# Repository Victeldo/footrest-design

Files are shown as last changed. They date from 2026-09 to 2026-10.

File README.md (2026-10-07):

# Flat-pack footrest — design and experiment history

**Looking for the parts to print? Start in [current/](current/README.md): the complete current set, materials, quantities and foot placement.**

Local engineering repository reconstructed on 2026-09-20 from supplied files, workspace artifacts and the user messages in this conversation. Each available design stage has its own chronological commit and tag. Commits use their actual creation time; they are not the original design timestamps.

Read [STATUS.md](STATUS.md) before using any print files, then [CHANGELOG.md](CHANGELOG.md). Each directory under `versions/` contains preserved artifacts and a `REVIEW.md` explaining the change, reason, evidence, outcome and next question. [CONTRIBUTING.md](CONTRIBUTING.md) sets the process for future iterations.

## Evidence and provenance

- `provenance/files.json` maps copied files to workspace paths and SHA-256 hashes. Paths are relative to the original project workspace, not this repository.
- Original files are copied without rewriting their contents. Some README files were annotated later in the project; they are preserved as found, not represented as exact release-day snapshots. Their print instructions can be obsolete.
- `archives/` retains original ZIP exports, which may contain earlier documentation than the unpacked artifacts. Historical print instructions are not current recommendations.
- Test observations in REVIEW files are retrospective summaries of user messages, not instrumented measurements. They distinguish local fit from assembled performance. Source reports preserve the recorded CAD evidence; this repository import does not rerun CAD, FEA or printer tests.
- V4 and earlier failed disconnected-brace versions have historical mentions but no standalone supplied geometry. No missing geometry or measured result has been invented.
- No GitHub remote, publication, license grant or external upload is implied. Existing local Git identity is used for the reconstruction, not claimed as authorship of all inherited geometry.

## Browse

`git log --oneline --reverse` shows the sequence. `git show <tag>` shows a stage's import and review. `git diff <old-tag> <new-tag> -- CHANGELOG.md` shows the recorded transition. Geometry snapshots have different paths: use `git diff --no-index <old-source.scad> <new-source.scad>` for a direct source comparison (exit 1 means differences).

Archived scripts vary in portability. Scripts named `validation_workspace.py` rely on original workspace paths. Do not assume relocating them makes them runnable. Preserved reference meshes and raw validation outputs are evidence, not additional parts to print.

Import audit: `provenance/output_coverage.json` accounts for every original output file by hash, including duplicate download folders. Original handoff files were also hash-verified. Large tool runtimes/caches and unrelated workspace scratch are intentionally excluded.

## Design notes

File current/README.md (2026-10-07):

# Current iteration — complete V10A print set

Start here instead of searching historical version folders. This folder collects the current assembly's parts; it is not a new geometry revision. Existing printed parts do not need reprinting.

## Print quantities

PLA:
- `PLA/01_top_PRINT_1.stl` — ONE top. Unchanged V7/V9 top; reuse yours.
- `PLA/02_left_support_PRINT_1.stl` — ONE V10A left support.
- `PLA/03_right_support_PRINT_1.stl` — ONE V10A right support. Do not print two lefts.
- `PLA/04_rear_brace_PRINT_1.stl` — ONE V10A side-entry rear brace.

TPU 95A:
- `TPU95A/05_foot_A_PRINT_2.stl` — TWO feet of variant A.
- `TPU95A/06_foot_B_PRINT_2.stl` — TWO feet of variant B.

Complete assembly: eight printed pieces. If your PLA assembly is already printed, only the four TPU feet are needed. Print TPU separately from PLA, with the orientations supplied and the settings that worked for your V6A shoe. A and B can share a TPU plate. Do not mirror or scale them in the slicer.

## Where the feet go

“Left/right” means viewed from the front of the footrest, facing toward the rear X-brace:

- Left support, front corner: A.
- Left support, rear corner: B.
- Right support, front corner: B.
- Right support, rear corner: A.

Thus A occupies one diagonal and B the other. Each support uses one of each. The window in the taller shoe wall aligns with the support's raised catch; on V10A these catches face inward. The closed shoe end goes at the outer end of the bottom rail. Seat the shoe and check the catch appears in the window; peel the window wall away deliberately for removal rather than forcing the PLA catch.

These are the original V6A-derived shoe geometries, preserved byte-for-byte from the V9 full pack. The mirrored V10A arrangement was checked on 2026-10-07: all four shoes can be positioned using ordinary rotations/translations (no new reflected print required), with zero nominal interference against the assembled structural parts. Physical fit on your actual V10A prints remains to be confirmed. This check is not a grip or fatigue test.

## Current experimental status

V10A reportedly substantially improved racking stability. The fully seated top reportedly binds during straight removal; packability remains unresolved. No load rating or measured 200 N qualification exists. Feet are for grip/floor protection, not a cure for structural racking. See [latest status](../STATUS.md).

## Provenance and updates

`manifest.json` records quantities, exact versioned sources and SHA-256 hashes. `foot_compatibility_checks.json` records the four rigid placement transforms and interference results. All six STLs are unchanged copies of their source version; only filenames and organization changed.

When a future iteration is accepted for testing, refresh this folder and quantities/manifest in the same commit. Preserve historical artifacts under `versions/`. Current means latest selected prototype assembly, not certified/final.

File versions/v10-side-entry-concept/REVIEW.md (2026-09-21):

# V10 side-entry concept — discussion model, not a print release

Parent: V9 bracket V2 and its assembled racking/lift-off failure. New concept created 2026-09-20. No physical tests have been run on V10.

## Agreed design boundary

Preserve the top where practical. Preserve the support frame and TPU interfaces where practical, but allow rear interfaces on both supports and brace to change. Reuse of existing support prints is a preference, not an acceptance criterion. User rejected purchased fasteners and chose investigation of inward-facing horizontal sockets. A stop added to the old drop-in system is not the selected path.

## Observation and hypothesis

V9/V2 upper channels slid upward off their rails during left/right racking. Smaller clearance improved stability but did not prevent the failure. Timing of initial channel lift versus initial racking remains unmeasured.

Hypothesis: restricting vertical movement at the brace attachment points removes a motion that defeats the rear X. Sideways sockets provide roofs and floors without a separate latch. The installed top must then restrain sideways support separation. This is conditional capture, not a positive lock against every combined motion.

## Concept geometry

Four rectangular brace tongues enter inward-facing blind sockets. Nominal tongue section 8 mm fore-aft by 16 mm vertical; 12 mm engaged length, with 2 mm clearance to each blind end. Socket section 8.3 x 16.3 mm. These 0.15 mm clearances are a starting concept value, NOT transferred validation from the differently oriented V9C coupon.

Socket block envelope is 20 x 23 x 24 mm. The roof/floor thickness is 3.85 mm; no strength claim follows from that dimension. Blocks overlap the original rear rail rather than replacing it. Gusseting, fillets, print orientation and material consumption are not finalized. The inward projection moves the X attachment centers closer together (144 mm across by 160 mm vertically); member forces must be re-evaluated rather than inheriting the V9 structural assumptions. X members remain nominally 8 x 6 mm.

Left and right support concepts are mirrored in assembled coordinates. This changes the handedness arrangement from the original identical-support V9 build. A print-orientation and TPU handedness review is still required; do not infer that existing shoes or two identical prints are already reconciled. The top uses the existing V7 geometry through the preserved source module.

## Assembly and force transfer

With the top off, bring supports inward around the brace. Each tongue slides sideways into its socket until its shoulder meets the mouth. Fit the top over the support tabs last. To disassemble, remove top and move supports outward.

Upward/downward tongue motion meets socket roof/floor after nominal clearance is taken up. Sideways withdrawal requires support separation. With the top held seated and rigid, its existing tab/socket walls oppose that separation. This is the reason to investigate the mechanism, not proof of assembled stiffness.

The top is not latched down. The CAD checks hold it seated/fixed when probing support separation and splay. They do not show whether racking can lift the top, rotate or flex supports, crack a roof, or gradually withdraw a lower tongue. That coupled motion is the remaining critical issue. A part with a closed socket can still have excessive angular or elastic compliance.

## Checks actually run

- Four rendered components: one connected, watertight, consistently wound mesh each.
- Assembled nominal overlaps: numerical zero.
- Both supports moving outward/inward 0–16 mm in 0.25 mm steps with brace fixed and top absent: no interference.
- Top installation over 0–40 mm in 0.5 mm steps: no interference.
- Deliberate brace displacement up/down by 0.5 mm: blocking contact at the sockets.
- Deliberate support outward movement of 0.2 mm with top fixed: blocking contact.
- Left-support rotation probes about its top at 0.1, 0.25, 0.5, 1 and 2 degrees also meet the fixed top. These are rigid geometric obstruction probes, not allowable-angle/stiffness predictions.

See concept_checks.json. No FEA, physical test, slicer review, deformable-contact simulation or print-size/orientation qualification is claimed. A clean nominal insertion path does not establish comfortable simultaneous insertion in a printed four-joint assembly.

## Deliverables and next decision

V10_assembly_sequence.png shows the actual mesh assembly stages and a nominal y=165 mm joint section. V10_CONCEPT_ONLY.glb is a reference model, not a printable file. V10_concept.scad defaults to the assembly and exports component geometry in assembled coordinates. No printable STLs have been released.

Before a coupon: examine combined top lift/support splay and finalize the mirrored support/foot arrangement and print orientation. The concept must constrain racking with the real top seated, allow intentional disassembly, and remain simple enough for repeated packing. If that cannot be achieved cleanly, reconsider the capture principle rather than rely on friction.

Rebuild nominal checks with `python build_and_check.py --openscad /path/to/OpenSCAD` after installing requirements.txt. It uses temporary mesh exports, writes the check report, and does not release print files.

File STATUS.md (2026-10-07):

# Current stage: V10A — user-reported assembled stability improvement

On 2026-09-21 the user reported that V10 largely resolves racking and feels much more stable. This is qualitative assembled feedback for the supplied V10A release, not a quantified strength or durability pass. V9/V2 failed racking/retention previously. No load rating exists.

## Current direction agreed with user

Keep the top where practical; allow support rear interfaces and brace to change. Stay fully printable, without purchased fasteners. Investigate horizontal brace tongues captured between inward-facing support sockets, with the top fitted last. Do not hard-constrain the design to existing support prints or resume tightening V9.

[Concept and evidence](versions/v10-side-entry-concept/REVIEW.md). The new sockets block vertical tongue movement nominally; the top blocks outward support translation only while held seated in the checked model. Combined top lift/support splay, flexibility, strength, printability and mirrored TPU arrangement are unresolved. V10A print-oriented STLs are released; initial assembled stability feedback is positive. See versions/v10a-print-prototype/START_HERE.md.

Preserve the current geometry. Next establish whether intentional disassembly/reassembly remains comfortable and the improved stability persists. Top lift, measured loads, sustained behavior, cycling and TPU installation were not reported. Do not infer they passed.

## Preserved constraints

A1 256 mm cube, PLA structure, replaceable TPU95A shoes, seated use, no standing. Existing top 240 x 170 mm, nominal overall height 241 mm. Calibrated top tabs 7 x 22 x 7 mm into 7.10 x 22.10 mm sockets. 200 N remains an unverified check target. Low filament waste, simple packing and deliberate easy disassembly are acceptance criteria.

## Latest packability observation

After fully seating the top, the user reports straight withdrawal feels locked and angling helps. This is not intentional latch behavior. Easy disassembly remains unresolved. Diagnose the actual binding location before changing the calibrated sockets, and avoid forceful extraction.

## Complete print set

Use [current/README.md](current/README.md) for all required parts and quantities. On 2026-10-07 the existing two A/two B shoes were verified geometrically on the mirrored V10A supports. No new foot geometry or physical fit result is implied.

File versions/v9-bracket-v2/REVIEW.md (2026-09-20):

# V9 bracket V2 with four 0p15 channels

Stage: `v9-bracket-v2`. Previous recorded stage: `v9c-fit`. Retrospectively documented 2026-09-20.

## Change and reason

Applied tested 0.15 mm fit to all four brace channels; X, spacing, top and supports unchanged. No anti-lift feature. About 0.53 g solid PLA added over prior brace.

## Recorded CAD/analysis evidence

Recorded one watertight component, A1 envelope, nominal assembly/removal/top-install checks. Regression against old brace plus four tighter coupons differed 0.00994 mm³ within documented 0.02 mm³ numerical tolerance.

## User-reported physical evidence

User printed V2: more stable, but during left/right racking the upper channels again slid up off the T rails. User emphasized that the brace still does not prevent racking.

## Outcome and next question

FAILED full-frame racking/retention despite improved local fit. Further tightening is not the established fix. Open question: when does vertical channel motion begin relative to frame racking? A proposed anti-lift feature must carry load and constrain racking, not merely catch a detached brace.

## Provenance caveat

Copied artifacts and archives are preserved as found. Some source READMEs contain later annotations or stale release instructions. This review and repository STATUS take precedence for interpreting current experimental status. No CAD or physical tests were rerun during this history import.

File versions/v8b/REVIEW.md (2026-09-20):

# V8B tether-eyelet keeper trial

Stage: `v8b`. Previous recorded stage: `v8`. Retrospectively documented 2026-09-20.

## Change and reason

Added receiver/keeper eyelets for cord retention. Initially considered TPU tether, but actual deliverable assumed cord; no TPU tether attachment was validated. Provisional rearward locations studied for key access.

## Recorded CAD/analysis evidence

Recorded joint mesh/path checks and four provisional key-clearance paths against top/support core. Attachment webs, full brace integration, tether motion and human access were not complete.

## User-reported physical evidence

No physical V8B pass reported. User questioned increasing complexity; assistant agreed keys/posts/tethers were overcomplicating the problem.

## Outcome and next question

Abandoned. Return to whole-assembly sequence and simpler connections rather than iterating an elaborate lock.

## Provenance caveat

Copied artifacts and archives are preserved as found. Some source READMEs contain later annotations or stale release instructions. This review and repository STATUS take precedence for interpreting current experimental status. No CAD or physical tests were rerun during this history import.

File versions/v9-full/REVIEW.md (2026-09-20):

# V9 full assembly with backed rail roots

Stage: `v9-full`. Previous recorded stage: `v9-trial`. Retrospectively documented 2026-09-20.

## Change and reason

Kept coupon contact geometry; added backing at each T root, with roughly 183 mm³ net added per support. Released full support/brace and unchanged top/TPU parts.

## Recorded CAD/analysis evidence

Recorded full topology/bed checks, four-joint assembly/removal and top installation, TPU nominal intersections, plus top/brace regressions. Root review was qualitative, not strength qualification.

## User-reported physical evidence

One support plus brace slid smoothly but swayed; user flagged this before printing second. Assistant expected the second support to constrain it. Complete assembly without TPU feet racked with all floor corners touching. Upper C channels slid upward off T rails; they did not spread/pop backward. User described the frame becoming a parallelogram.

## Outcome and next question

FAILED assembled racking/retention. Earlier confidence in the second support was unsupported. Floor grip was not the identified cause. Keep top/supports for experiments, not as a rated structure.

## Provenance caveat

Copied artifacts and archives are preserved as found. Some source READMEs contain later annotations or stale release instructions. This review and repository STATUS take precedence for interpreting current experimental status. No CAD or physical tests were rerun during this history import.

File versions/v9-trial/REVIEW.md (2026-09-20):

# V9 drop-in T/C coupon and full-layout concept

Stage: `v9-trial`. Previous recorded stage: `v8b`. Retrospectively documented 2026-09-20.

## Change and reason

Adopted four short T rails with C channels, fixed lower seating ledges and 20 mm vertical engagement. No latch. Beveled 45-degree shoulders for flat-print geometry; 0.30 mm per axis face. Narrowed ledge after detecting diagonal interference.

## Recorded CAD/analysis evidence

Recorded connected coupon/support/brace meshes, full approach/vertical paths and top install checks. Existing top explicitly did not block lift-off. Strength, uplift and four-point physical fit remained unknown.

## User-reported physical evidence

Coupon slid easily and remained wrapped during X/Y motion, with some rocking. User highlighted looseness. This was a local fit test only.

## Outcome and next question

Advanced to full prototype without proof of racking restraint. Later failures showed that easy fit and wraparound engagement were insufficient.

## Provenance caveat

Copied artifacts and archives are preserved as found. Some source READMEs contain later annotations or stale release instructions. This review and repository STATUS take precedence for interpreting current experimental status. No CAD or physical tests were rerun during this history import.

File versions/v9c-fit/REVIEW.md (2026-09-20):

# V9C brace-side clearance coupons

Stage: `v9c-fit`. Previous recorded stage: `v9-full`. Retrospectively documented 2026-09-20.

## Change and reason

Reduced only channel clearance to 0.20 and optional 0.15 mm per face, maintaining engagement, exterior, supports and top. No anti-lift stop added. Goal: distinguish excess clearance from the unrestricted release direction.

## Recorded CAD/analysis evidence

Recorded original-0.30 reproduction, single-solid tighter exports, added-material-only check, and nominal approach/vertical paths against support rail positions. No revised full-frame test at this stage.

## User-reported physical evidence

User reported 0p15 felt pretty good and authorized full bracket V2. Separate 0p20 result and explicit all-four-rail/cycle confirmation were not supplied.

## Outcome and next question

Local 0p15 fit selected. This did not prove racking or lift-off solved.

## Provenance caveat

Copied artifacts and archives are preserved as found. Some source READMEs contain later annotations or stale release instructions. This review and repository STATUS take precedence for interpreting current experimental status. No CAD or physical tests were rerun during this history import.

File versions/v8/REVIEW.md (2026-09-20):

# V8 sliding tongue and loose quarter-turn keeper

Stage: `v8`. Previous recorded stage: `v7`. Retrospectively documented 2026-09-20.

## Change and reason

Separated structural sliding tongue (0.30 mm per face) from quarter-turn withdrawal keeper. Added lift-to-turn locating posts and exposed grip to avoid forceful disassembly.

## Recorded CAD/analysis evidence

Recorded connected watertight meshes, sampled insertion/lift/rotation/extraction paths and deliberate blocking collisions. No load validation.

## User-reported physical evidence

No successful printed V8 trial reported. User flagged four loose keys as a loss/usability issue; print was canceled as the design changed.

## Outcome and next question

Abandoned before physical validation. Added operations/loose parts were unacceptable for packing.

## Provenance caveat

Copied artifacts and archives are preserved as found. Some source READMEs contain later annotations or stale release instructions. This review and repository STATUS take precedence for interpreting current experimental status. No CAD or physical tests were rerun during this history import.

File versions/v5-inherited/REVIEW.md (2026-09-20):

# Inherited V5 lightweight support and friction shoe

Stage: `v5-inherited`. Previous recorded stage: `v3-inherited`. Retrospectively documented 2026-09-20.

## Change and reason

Inherited 10 mm perimeter rails, 8 mm X members, 7 mm thickness and local junction pads. Handoff describes reduction from unavailable V4 (12 mm rails/10 mm braces). Existing TPU shoe relied on friction only.

## Recorded CAD/analysis evidence

Handoff reports a connected support and roughly 80.17 cm³ volume. Later V6A checks preserved the full bottom rail. No structural rating was established.

## User-reported physical evidence

No standalone V5 structural load result is available. User requested proper replaceable TPU retention.

## Outcome and next question

Use as structural starting point; replace friction-only foot interface without cutting the rail.

## Provenance caveat

Copied artifacts and archives are preserved as found. Some source READMEs contain later annotations or stale release instructions. This review and repository STATUS take precedence for interpreting current experimental status. No CAD or physical tests were rerun during this history import.

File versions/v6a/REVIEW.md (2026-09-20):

# V6A mechanically retained TPU foot

Stage: `v6a`. Previous recorded stage: `v6-calibration-inherited`. Retrospectively documented 2026-09-20.

## Change and reason

Added external PLA corner catches and mating TPU window shoes, keeping the bottom rail intact. Replaced friction-only retention with an intentional peel-to-release interface.

## Recorded CAD/analysis evidence

Recorded component/watertightness checks, material-preservation booleans, nominal contacts, rigid blocking checks and independent SCAD export comparison. Found inherited disconnected top bosses and 243 mm provisional height with sole.

## User-reported physical evidence

User printed shoe and PLA key/coupon, reported it fit and passed the tests. Small internal gap opposite the key slot was reported. Exact forces and per-test cycle counts were not supplied.

## Outcome and next question

Local TPU interface accepted for reuse; not full-structure validation. Next reconcile top/height and across-width bracing.

## Provenance caveat

Copied artifacts and archives are preserved as found. Some source READMEs contain later annotations or stale release instructions. This review and repository STATUS take precedence for interpreting current experimental status. No CAD or physical tests were rerun during this history import.

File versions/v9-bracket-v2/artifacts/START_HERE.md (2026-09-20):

# Rear bracket V2 — tested 0p15 fit

Print ONE PRINT_V9_bracket_V2_0p15_PLA.stl. It replaces the loose original V9 rear bracket. Keep your existing printed top and both supports.

All four channels now use the successful 0p15 coupon geometry: 0.15 mm nominal clearance per axis-aligned face, approximately 0.21 mm normal to the angled shoulders. Engagement remains 20 mm. X members, outside dimensions, joint spacing and assembly orientation are unchanged. No latch or anti-lift stop has been added.

## Print

Use the same PLA and slicer settings as your successful 0p15 coupon. Preserve the supplied orientation: flat X/back face on the bed, channels facing up. Size: 217 x 180 x 13.6 mm, within the A1 envelope. Inspect the sliced shoulder overhangs and channel openings. No new sliced toolpaths were generated or verified here. Solid-volume estimate is approximately 45.4 g; actual filament use comes from your slicer. The change adds about 0.53 g solid PLA over the previous bracket.

If you have not already done so, try the successful 0p15 coupon on all four actual rails before starting this larger print. Do not force it onto a rail that differs from the one originally tested.

## Assemble and evaluate

Remove the old rear bracket. With the top removed, align all four channels about 21 mm above their seated positions, approach from behind and lower straight down onto the stops. Guide at the joint blocks; do not bend the X to force four-point alignment. Install the existing top. All four channel backs should rest on their ledges.

Before applying foot load, gently alternate sideways pressure with the assembly on a flat floor. Compare racking against the original bracket and watch the upper AND lower connections for upward movement. Stop for climbing, binding, cracking, whitening or a floating corner. Confirm hand removal remains practical, supporting the side frames while lifting the bracket.

A closer local fit does not prove full-frame stiffness or anti-lift behavior. If V2 still climbs, reduced clearance alone has not solved retention. No 200 N capacity or normal-use qualification is claimed. Report seated play, racking, corner lift and removal effort before further load testing.

## Geometry validation

The exported and reloaded bracket is one connected watertight solid with consistent winding. All four nominal channels clear the current supports in the assembled position and sampled 21 mm vertical release/raised rear approach paths (0.25 mm increments). The existing top's installation path was sampled at 0.5 mm increments. All collision checks returned zero volume.

The full mesh was compared against the old brace unioned with four copies of the tested 0p15 coupon. Symmetric difference was 0.00994 mm³ over roughly 36,600 mm³, within a 0.02 mm³ numerical tolerance for STL/float coordinate rounding. This verifies the intended channel-only revision to mesh precision. See geometry_checks.json for dimensions, checks and hash.

Source: V9_bracket_V2_0p15.scad is self-contained and exports the full bracket directly. validation_workspace.py records the validation using the existing project reference meshes; it is not a standalone rebuild tool.

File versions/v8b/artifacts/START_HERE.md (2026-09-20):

# V8B: tethered-key usability trial

V8's loose-key trial is superseded. This is one small joint coupon, not a full footrest release. The current working assumption is a short cord tether; no TPU tether attachment has been validated or released.

## What changed

A 4 mm eyelet was added outside the receiver socket wall. A 3 mm eyelet was added through the keeper handle tip, away from its central shaft. A cord tied between these eyes keeps the key attached after removal, including when the parts are turned upside down. The tether carries only the loose key, not structural brace loads. It is replaceable by untying/cutting the cord. It does not prevent the unlocked key from dangling and does not make the lock vibration-proof.

The sliding tongue, 0.3 mm clearance per face, quarter-turn crossbar and lift-to-turn locating posts are unchanged. No support rail, top connection or TPU foot interface has been cut or revised.

## Print one joint

Print one each: V8B_trial_receiver.stl, V8B_trial_tongue.stl, V8B_trial_keeper.stl. All PLA, same plate, normal by-layer printing. Keep supplied orientations. Starting profile: 0.4 mm nozzle, 0.2 mm layers, 6 walls, 5 top/bottom layers, your previous PLA settings. No supports intended; inspect the 12.6 mm receiver cavity bridge, 12.2 mm tongue opening bridge, and smaller keeper/eyelet openings in the slicer. Geometric printability has been reviewed, but no slicer/toolpath or physical print validation was performed here.

Total solid-volume estimate: 13.7 g PLA at 1.24 g/cm³; use the slicer for actual consumption. Do not print full-size replacements yet.

## Fit and tether test

1. Check that the tongue slides freely in and out of the receiver with the keeper absent. Stop if it wedges; do not hammer it.
2. Insert the keeper across the elongated hole, leaving the handle about 1.8 mm above its seated position. Turn 90 degrees and lower between the posts. A gentle withdrawal tug should be blocked.
3. Lift about 2 mm, turn back, and remove the keeper; then slide the tongue out. Repeat a few times before fitting a tether.
4. Use flexible cord around 0.8–1 mm diameter. Tie one end through each eyelet, leaving approximately 60 mm of free cord between attachments plus sufficient knot tails. This length is a starting trial value, not a tested optimum. Tie around the eyelet material rather than relying on a small stopper knot being larger than the hole. Tug-check each attachment. Keep knots outside the locking surfaces.
5. Repeat ten lock/release cycles with the cord attached. The keeper must lift and turn without pulling the tether taut, and the cord must not enter the tongue socket or locating posts. The released keeper should stay attached when the coupon is inverted and gently shaken. Check the knots and eyelets afterwards.
6. Report finger effort, whether two hands feel awkward, any cord snagging, and whether locked/unlocked is easy to identify. Stop for whitening, cracking, wedging, or a loosening tether. These are usability trials, not body-weight tests.

When locked, the handle runs along the tongue's sliding direction and sits down between the posts. When released, it turns across that direction. This orientation is the current visual/tactile cue; printed LOCK labels and a stow position are not yet implemented.

## Validation completed

All three meshes are watertight, consistently wound, one connected component each, with positive volume. Largest part dimension is 32.3 mm. Sampled joint insertion, lift, rotation and extraction have no significant Boolean overlap (numerical residue under 1e-12 mm³). Deliberate wrong-direction tests confirm geometric blocking of tongue withdrawal, excessive locked lifting and seated rotation. See geometry_checks.json.

Four provisional receiver origins are [25.55 or 221.55, 168, 33 or 193] mm in assembled coordinates. At all four, the sampled keeper release paths clear the existing top and unchanged support cores/rail stiffeners. Retired V7 rear sockets are omitted from that context. See layout_checks.json and V8B_access_study.png. The illustration omits the new brace and attachment webs; the receivers are not integrated structural parts.

This is NOT a completed four-joint assembly validation: new connecting webs and brace, tether motion, human finger access, and strength are still outstanding. Moving receivers rearward creates a larger offset from the rail, so the attachment must resist the corresponding bending moment. Their supports must be designed before full-size export. The upper connector path clearing the top does not alone prove comfortable hand access.

The tether does not improve tongue/keeper strength. The 2.9 mm tongue ligaments beside the opening remain a structural trial detail. Neither V8 nor V8B establishes the provisional 200 N footrest capacity. Once usability is acceptable, the full assembly needs reinforcement, geometry checks, print review and physical loading checks.

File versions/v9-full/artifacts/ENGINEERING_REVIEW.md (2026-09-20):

# V9 full-prototype joint review

## What the physical trial established

The channel slides on by hand, remains wrapped around the rail while moved in X/Y, and can rock slightly. This supports retaining the current clearance for the full-assembly experiment. It does not quantify stiffness, four-joint alignment, uplift behavior or strength. More contact points do not eliminate clearance.

## Root and shoulder decisions

The 20 mm-long engagement, 14 mm T head, 7 mm stem, 3.2 mm channel side walls and 6 mm rear wall are retained. Nominal clearance is 0.3 mm per axis-aligned mating face and about 0.42 mm normal to the 45-degree shoulders. The section is constant along the vertical sliding direction; it does not wedge tighter as it seats.

The C shoulders oppose backward separation by bearing on the T shoulders. Their slope produces a spreading component in the channel walls, so shoulder/root cracking remains an inspection item. Side faces transfer across-width forces. The short 11 x 6 mm nominal seating patch on each ledge stops downward travel, but cannot provide tensile vertical restraint. Four such joints therefore cannot be modeled as four fully fixed or pinned connections: upward contact can open.

A 10.5 x 6 x 26 mm backing envelope is added to each rail root, mostly overlapping existing support material. It connects the previously short embedded stem to more of the rear rail. Its rear edge stops at the original rear-face plane; the moving channel starts 0.7 mm behind that plane. Only about 183 mm³ net material is added per support. This is a geometric load-path improvement, not a measured strength gain. No mating face or existing support member is cut.

The original 8 x 6 mm X members are retained in the brace, with a fused central crossing and broad overlap into the four channel backs. These distribute racking through axial forces and local bending, but slip and uplift may dominate apparent stiffness. The existing top geometry and calibrated tab/slot fit are preserved.

## Why this is a prototype release

The full model has no interference along the intended assembly paths. Connectivity and bed envelopes have been checked. That is enough to build the assembly-test prototype following the successful local fit test. It is not enough to assign a load rating.

No FEA, printed-material allowable stress, fatigue qualification, creep prediction or anti-lift validation was performed for this release. The earlier V7 idealized frame calculation assumed more constrained joints and cannot establish the V9 gravity-seated frame's stiffness or strength. In particular, neither self-weight nor a nominal 20 mm engagement proves that a connection cannot climb under cyclic racking.

The useful next observation is the assembled response: four-point seating, clearance take-up versus elastic movement, and any upward motion of a corner. If the frame climbs, a simple anti-lift provision would be justified by observed behavior; it has not been added preemptively.

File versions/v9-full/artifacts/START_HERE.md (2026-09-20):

> ASSEMBLY TEST FAILED: user reported racking and upper channels lifting off. Do not reprint the unchanged brace as a fix. Current next step: ../V9C_fit/START_HERE.md. Existing top/supports are retained for the fit revision.

# V9 full-size assembly-test prototype

The user-tested drop-in fit is retained. The channel and full brace are geometrically identical to the V9 concept. Each T rail now has a backing pad extending 6 mm into the rear rail region and 3 mm above/below its engagement, without entering the sliding channel. No separate key, cord or latch is required. No original rail material was removed.

## What to print

- V9_support_PLA_PROTOTYPE.stl: TWO identical copies, 164.3 x 230 x 14 mm. Print the first support and brace before committing the duplicate.
- V9_brace_PLA_PROTOTYPE.stl: ONE, 217 x 180 x 13.6 mm.
- V9_top_PLA_PROTOTYPE.stl: ONE, 240 x 170 x 24 mm. This is unchanged from V7; reuse an intact V7 top if already printed.
- V9_foot_left_TPU95A.stl and V9_foot_right_TPU95A.stl: TWO of each for four feet total. Reuse matching successful V6A/V7 feet. These interfaces are unchanged.

All STLs are in millimetres and oriented for printing. Do not mirror one support: both supports have their raised printing faces pointing in the same global direction in the assembled model. The brace is asymmetric through its thickness and aligns with these identical supports.

Use the material/profile that produced the successful V9 coupons, preserving their orientation-dependent fit. If using the previous baseline: 0.4 mm nozzle, 0.20 mm layers, 6 walls, 6 top/bottom layers, 20–30% infill. These are starting settings, not a strength qualification. Print TPU separately with your successful settings. No multi-material purge tower is needed.

The top prints smooth face on the bed. Supports print original flat face down. The brace prints its flat X/back faces on the bed, channels facing up. Inspect the channel shoulders, stop ledges and root additions in sliced preview. The coupon established the local fit/print approach, but the new backing pads and whole parts have not been physically printed. The short ledges include local overhangs; no automatic support generation or slicer validation was performed. Do not add supports inside the sliding surfaces without checking their effect on fit.

Center the 240 mm top: it leaves only 8 mm nominal margin on each side of the 256 mm plate. Check brim and exclusion areas. Do not scale any part. Each large part should have its own plate unless the slicer verifies another arrangement; printing two supports together is not assumed feasible.

Actual filament consumption must come from the slicer. The earlier reported V7 masses are historical, not V9 predictions. The root backing adds only about 0.23 g solid PLA per support over the V9 concept.

## Low-waste print order

1. Print one support and the rear brace. Engage both joints on that one support, then lift the brace off. Check simultaneous seating, easy removal and no root whitening. Do not use the cantilevered brace as a lever or load this partial assembly.
2. If both joints slide and seat as expected, print the second identical support. Reuse or print the unchanged top and TPU feet.
3. Assemble the complete prototype and assess whole-frame behavior below. No further isolated coupon is requested.

## Assembly

Fit one left and one right TPU shoe to each support. Place both supports upright with their rear T rails at the same rear edge, and both raised printing faces pointing the same global direction; use the assembly image as the orientation reference. Hold them about 196 mm apart at their center planes.

With the top off, align the brace channels roughly 21 mm above their seated positions. Approach from the rear and lower all four channels together onto their stops. Guide at the joint blocks rather than bending an X member to force alignment. Install the top over the four calibrated tabs; the support shoulders should seat against the top.

The four C backs should sit on their ledges. Print variation may prevent perfect four-point seating; if one corner floats, report it instead of forcing or sanding the assembly immediately. Reverse the sequence for packing: remove the top, support the side frames, lift the brace about 21 mm and separate.

The top does NOT positively block brace lift-off. Lift-off is the intended release mechanism. Carry disassembled or support the components together; do not assume lifting by the top or brace retains the rest.

## Full-assembly evaluation

First check all four feet touch a flat floor and all top shoulders and brace stops seat. With hands at the top, gently alternate lateral pressure in both directions while watching each C channel. Distinguish a small initial clearance take-up from continuing flex, clunking or a corner rising off its stop. Record a short view of the rear if the motion is difficult to describe.

Stop for joint climbing, increasing movement, whitening, cracks or an unseated top. If the assembly remains stable, introduce seated heel pressure gradually while keeping your weight on the chair and inspect again. Do not stand on it. This initial check does not certify the provisional 200 N target, cyclic durability or long-term creep. An agreed measured-load test can follow the seating/racking results; normal use is not yet validated by CAD.

## Completed checks

Each exported mesh was reloaded and verified as one connected, watertight component with consistent winding and positive volume. All object envelopes fit the A1 bed. Nominal full-assembly interference is numerical zero, including all four TPU feet. Vertical brace travel and raised rear approach were sampled every 0.25 mm; top installation every 0.5 mm. No collision was found. The brace and top were Boolean-compared against their previous versions and are identical.

These checks do not simulate printed tolerances, human assembly force, elastic deformation or layer strength. See geometry_checks.json for measurements and hashes, ENGINEERING_REVIEW.md for joint reasoning, and V9_full_assembly.png for orientation.

## Rebuild

Install OpenSCAD and the Python packages in requirements.txt, then run `python build_and_validate.py --openscad /path/to/OpenSCAD`. This rerenders the five parts, repeats validation and writes the STLs/report next to the source. The reference meshes are regression inputs, not additional print parts.

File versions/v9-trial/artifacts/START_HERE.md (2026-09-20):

# V9: drop-in T-and-C joint — print these two coupons only

V8 and V8B keys/tethers are superseded. V9 uses four short rails, four integral brace channels and fixed seating ledges. No loose fasteners, flexing latch or wedge fit. The existing top does NOT trap the brace: it can lift off. This is a gravity-seated concept, not positive anti-lift retention.

## Print

Print one PRINT_FIRST_V9_rail_coupon.stl and one PRINT_FIRST_V9_channel_coupon.stl. Both PLA, same plate, normal by-layer printing; retain supplied orientations. Start with your existing PLA profile, 0.4 mm nozzle, 0.2 mm layers, 6 walls, 5 top/bottom layers. Supports are not intended. Review the slicer: the 45-degree internal shoulders replace unsupported square lips. The rail has separate initial bed-contact regions that merge as printing progresses; check bed adhesion. No slicer/toolpath verification has been performed here.

Together the coupons contain 8.48 cm³, about 10.5 g if solid PLA at 1.24 g/cm³. Actual slicer consumption depends on settings. Do not print the full support/brace context selectors yet.

## Test

1. Hold the rail upright: its long 20 mm engagement runs vertically, and the seating ledge is at the bottom.
2. Put the channel above the rail, with its narrow opening facing the rail stem. Lower it straight down until its solid back lands on the ledge. Do not push it on from the rear at the seated height.
3. Lift roughly 21 mm to clear the rail completely, then separate. It should be finger-easy in both directions. No hammering, prying or forceful snap is intended.
4. Repeat ten cycles, checking for rough sliding, binding, whitening or wear. Report whether it falls into place under its own weight or requires light hand pressure, plus side-to-side/backward play.
5. Gently pull straight backward while seated: the shoulders should prevent separation. Gently push downward: the ledge should stop travel. This is only a fit/handling test; do not load it with body weight.

Do not sand extensively to make it pass without reporting that: the goal is to assess the printed clearance. A single joint passing does not prove four simultaneous joints will align or remain seated under racking.

## Mechanics and dimensions

T head: 14 mm across, 4 mm rear portion; stem: 7 mm. Vertical engagement: 20 mm. C outer width: 21 mm. Side wall thickness beside the head: 3.2 mm; rear wall: 6 mm. Axis-aligned mating faces have 0.3 mm clearance per face; matching 45-degree shoulders have approximately 0.42 mm normal clearance. These are uncalibrated trial values. The joint is constant-section along its travel, not tapered to wedge tight.

The angled shoulders preserve wraparound retention while improving flat-print overhangs. They can also spread the C walls when loaded backward; wall/root strength requires physical assessment. Fillets and local reinforcement remain candidates before final structural release.

The T attachments add material behind the existing rail rather than cutting into it. Their offset still creates bending at the attachment root: unchanged rail material does not prove unchanged strength. The top interface and V6A foot geometry remain unchanged. Both supports use the same orientation, matching the existing design.

## Geometry validation

Both coupons, the full support concept and full X-brace concept are each single connected, watertight meshes with consistent winding and positive volume. Print envelopes fit the A1: support 164.3 x 230 x 14 mm; brace 217 x 180 x 13.6 mm. See geometry_checks.json.

Boolean checks sampled 0.25 mm steps over the 21 mm vertical engagement/release path and raised rear approach, for the coupon and all four full-assembly connections together. No interference remained. Top installation was checked at 0.5 mm increments over 30 mm; the assembled top/support/brace do not interfere. Deliberate 0.5 mm downward, 1 mm backward and 1 mm sideways motions produce contact/interference as expected, establishing the ledge and wraparound geometry. These checks are nominal rigid CAD checks, not print-tolerance, strength or fatigue proofs.

An initial upper-stop/diagonal clash was corrected by narrowing the stop to 11 mm. The rear wall has a nominal 11 x 6 mm seating patch. The stop is not a latch.

## Full assembly sequence and remaining work

With the top removed, hold the brace 21 mm above its seated location, approach the supports from behind, align the four channels and lower onto the stops. Install the top. Reverse to pack. The current geometry also permits upward brace removal with the top present; no anti-lift benefit is claimed from the top.

After coupon fit succeeds, check simultaneous four-joint alignment and seating, then assembled racking and corner lift. Vertical seated-foot loading alone does not establish rear-brace stability. The 200 N target is not a tested rating. Full-size release is withheld pending fit feedback and further root/shoulder/load review.

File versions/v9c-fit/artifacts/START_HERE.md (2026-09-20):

# V9C: tighter C-channel fit tests for the EXISTING printed supports

The full V9 assembly racked and its upper C channels slid upward off their T rails. All floor corners contacted the ground. This is a failed assembled-brace test, not a TPU-foot issue. The printed top and supports are retained for this iteration; that does not establish their load capacity.

## Print only the 0p20 channel first

V9C_channel_0p20_PLA.stl reduces nominal axis-aligned clearance from 0.30 to 0.20 mm per face. Head pocket width changes from 14.6 to 14.4 mm, stem opening from 7.6 to 7.4 mm. The corresponding 45-degree shoulder normal gap changes from about 0.42 to 0.28 mm. This is an adjustment to BOTH lateral and fore-aft mating surfaces, not uniform scaling.

Use the same PLA, layer height, line widths, wall settings and supplied orientation as your full V9 brace. Flat back on the bed, channel upward. Do not rotate it upright, scale it, or sand mating surfaces before assessing the result. If the slicer requests mesh repair, stop and report that. The solid-volume estimate is 4.64 g at 1.24 g/cm³; actual slicer consumption may differ.

V9C_channel_0p15_PLA.stl is an optional tighter fallback, not a request to print both immediately. It uses 0.15 mm per face (14.3 mm head pocket, 7.3 mm stem opening, approximately 0.21 mm bevel-normal gap), about 4.69 g solid. Layer quantization and extrusion variation mean a 0.05 mm nominal change may not produce a distinct fit on every surface. Compare sliced layers if the two prints feel identical.

The pieces have no physical size labels. Print individually or label their exterior immediately if printing both. No new T-rail coupon, support or top is needed.

## Test against all four actual rails

Remove the top and rear brace for access, and hold each support securely. Slide the single test channel downward over a T rail to its ledge, then lift it off. Do not snap it on from the rear. Repeat on all four T rails, keeping track of support and upper/lower position.

The goal is easy finger-operated sliding with clearly less sideways/backward movement when seated. Hold close to the channel rather than applying leverage. Compare with the original loose coupon if available. Some upward sliding is unavoidable and intended; this test does not create an upward lock.

Repeat approximately ten cycles on each rail if initial movement is easy. Stop if it jams, needs force, shows whitening/cracks, or scrapes heavily. A fit that is good on three rails but binds on the fourth is not suitable for a four-channel brace. Do not force the tighter 0p15 part if 0p20 is already tight.

If 0p20 is comfortably removable on all four rails and removes most seated play, report that result; there is no need to chase the smallest number. If it is still clearly loose, try 0p15. Report insertion/removal effort, seated play and any difference among the four rails.

## What changed and what did not

Only the C-channel cavity shrinks. Exterior envelope remains 21 x 20 x 13.6 mm in print coordinates; engagement stays 20 mm. Material is added to the inner faces, not removed from structural walls. No latch, taper, extra fastener, support modification or top modification is introduced.

The 0.30 parameter version was Boolean-compared with the original V9 coupon and reproduces it. Both tighter exports are one connected, watertight mesh, with consistent winding and positive volume. Nominal approach and 21 mm vertical travel against the current full support at both joint heights were sampled every 0.25 mm with zero overlap. Intentional sideways/backward/downward overtravel produces blocking contact. Exported STLs were reloaded and checked. See geometry_checks.json.

These checks do not predict printed friction or deformation. No sliced toolpaths, material strength or full revised-brace test is claimed. Because the supports are identical, one nominal support geometry covers both sides; the physical test still needs all four printed rails.

## Next decision

After selecting the loosest variant that gives acceptable play and easy release across all four rails, update the full brace only, recheck its geometry and test the assembled frame again. A local fit test cannot demonstrate that four joints will register without binding or that the frame will resist racking.

Reduced clearance may reduce motion leading to lift-off. It does not physically prevent upward disengagement; continued climbing in the full assembly would mean this approach is insufficient. No replacement full-brace STL is released in this pack yet. Do not resume loading the loose V9 assembly pending the revised-brace test.

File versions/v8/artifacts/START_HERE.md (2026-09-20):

> SUPERSEDED: loose-key print canceled. See ../V8B/START_HERE.md for tethered-key trial status.

# V8 rear joint: print one small trial set

The V7 rear joint is retired after the printed brace key broke during removal and remained stuck in the support. Both prints are discarded. This release tests a new mechanism; it does not contain replacement full-size supports or a brace.

Print one each of V8_trial_receiver.stl, V8_trial_tongue.stl, and V8_trial_keeper.stl. All three are PLA and can share one plate with normal by-layer printing. No material changes or purge tower are needed. Keep the supplied orientations so the trial represents the intended structural parts. Use the same PLA/profile used previously, a 0.4 mm nozzle, 0.2 mm layers, 6 walls, and 5 top/bottom layers. Supports are not intended; inspect the small bridges in the slicer and after printing. Total solid-volume PLA estimate is 13.5 g at 1.24 g/cm³; use the slicer for actual consumption including brim/purge.

## Why this mechanism

The rectangular tongue has 0.3 mm clearance on each mating face (0.6 mm total). Its broad faces transfer brace loads through bearing contact. A separate quarter-turn keeper prevents withdrawal. This avoids requiring a structural tongue to be both an extremely tight fit and a hand-removable fastening.

The receiver is open-ended for inspection. The keeper's head seats between four posts, which obstruct rotation until the head is lifted. Its lower crossbar catches beneath the receiver when locked. This is a gravity-seated keeper, not a spring-latched or vibration-secured fastener: inverted transport retention is not established. For flat packing, remove and store the keeper separately.

## Trial sequence

1. Inspect bridges and remove only loose strings or brim. Record any sanding needed; extensive fitting would defeat this clearance test.
2. With the keeper removed, slide the blue tongue into the grey receiver until its broad pad meets the end. It must slide in AND out using fingers. If it wedges, stop; do not hammer or force it.
3. Align the keeper's long head and lower crossbar across the receiver's width, matching the elongated through-hole. Insert from above until the head remains about 1.8 mm above its seated height. The lower crossbar must have passed below the receiver.
4. Turn 90 degrees so the head runs along the tongue's sliding direction, then lower it between the indexing posts. A gentle withdrawal tug should be stopped by the keeper. Some clearance/play is intentional.
5. Lift the head about 1.8 mm (roughly 2 mm), turn 90 degrees back, and pull the keeper up and out. Then slide the tongue out. If the head will not rotate, inspect whether it clears the posts; do not twist forcefully.
6. Repeat 10 cycles. Report sliding effort without keeper, ease of lifting/turning/removing the keeper, play when locked, and any whitening, cracks, or wear. No body-weight test on this coupon.

See V8_release_sequence.png. Colors identify components only; one PLA spool is sufficient.

## Completed validation and limits

All three exported STL meshes have one connected component, consistent winding, positive volume, and are watertight. Largest dimension is 28 mm. Boolean overlap checks found zero collision at the assembled position and along sampled straight insertion (0.25 mm), lifting (0.05 mm), turning (0.5 degree), and keeper extraction (0.1 mm) paths. Deliberate out-of-path checks confirm tongue withdrawal by 1 mm hits the locked keeper, lifting the locked keeper by 3 mm catches the underside, and turning the seated handle by 15 degrees hits the indexing posts. These positive collision checks establish nominal geometric blocking, not strength.

The supplied receiver orientation includes a 12.6 mm tongue-cavity bridge and a 6.6 mm keeper-hole bridge. The tongue has a 12.2 mm keeper-hole bridge. These surfaces can reduce real printed clearance: inspection and the physical trial remain necessary.

The 18 mm tongue retains 2.9 mm of material on each side of its 12.2 mm-wide keeper opening. This is an intentionally small mechanism trial; neither those ligaments nor the receiver's attachment to a full support have passed a structural load test. Geometry checks do not establish fatigue life, impact strength, or the project's provisional 200 N vertical capacity.

If the trial passes, integrate the receiver into new full-size supports and the tongue into a rear brace, then validate the complete assembly, reinforcement, print orientation, release access, bed fit, and load path. The previously tested top connection and V6A TPU interface remain unchanged. Do not print another V7 rear connection.

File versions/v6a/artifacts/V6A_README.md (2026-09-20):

# V6A retained TPU corner foot — first physical trial

This is a coupon-stage design, not a validated final foot or full footrest. Print **one PLA coupon and one TPU foot**, inspect the fit, and return the observations below before printing full supports or duplicate feet. The supplied handoff was read before source and mesh inspection; its historical decisions were treated as design context. Original files are unchanged.

## Files and current status

- `V6A_PLA_corner_coupon.stl`: 32 × 22 × 9.2 mm representative bottom-left corner. PLA, flat original support face on bed, catch facing up.
- `V6A_TPU95A_test_foot.stl`: 29.8 × 11.1 × 16 mm in supplied print orientation. TPU 95A, sole on bed. No rotation or scaling needed.
- `V6A_retained_foot.scad`: editable native geometry. Default `part="coupon"`; use `"foot"`, `"coupon_assembly"`, `"support_reference"`, or `"support_assembly"`. The full support selectors are previews, not instructions to print a complete support yet.
- `V6A_interface_review.png`: mesh-derived views and cross-section.
- `geometry_checks.json`: baseline and new-part measurements and exact-solid intersection tests.
- `source_export_checks.json`: independent OpenSCAD 2021.01 export checks against the generated meshes.
- `reference/`: unchanged input files, for provenance only. Do not print the obsolete V5 foot or V3 top from this folder.
- `validate_and_build.py`: reproducible Manifold/Trimesh generator and geometry checks using the reference STLs. Dependencies are listed in `requirements.txt`. Run in a virtual environment with `python validate_and_build.py`; intermediate outputs go in `work/`. This validates default dimensions. Parameter edits in SCAD must be exported and checked anew; they do not automatically change the Python construction.

## Why this connector

The full 10 mm-high × 7 mm-thick V5 bottom rail, braces, gussets and top tabs are retained. Two small catches are added on the support's upper printing face, one near each lower corner. The catch root overlaps the existing material by 0.2 mm, so this is a solid union, not touching shells. No hole, slot, notch or rail thinning is introduced.

A groove cut into a thin rail can remove material from an important bending section and create a stress concentration. An external catch avoids that section loss. It still needs a physical test for catch-root damage and layer adhesion; preserving the rail section is not a load-rating calculation.

Each TPU shoe has a 2 mm sole, side walls, an outer-end stop and a through-window. The PLA bottom bears directly on the TPU sole. The catch is unloaded by ideal downward compression and primarily retains the shoe during lifting or dragging. In-plane handling forces meet the end stop or catch/window edges. The opposite side wall restrains motion across the 7 mm rail thickness.

The catch has a 45° entry ramp and a roof-shaped retaining edge. The window follows that retaining edge with nominal 0.25 mm vertical clearance, distributing capture across its width. Pull-off requires the window wall to flex outward over the catch, rather than merely overcoming surface friction. For replacement, deliberately peel that wall outward and withdraw the shoe toward the floor. This is positive geometric retention, but release force and fatigue are not yet established.

The roof-shaped window narrows to a 2 mm bridge at its top. This avoids asking TPU to bridge the full 10.5 mm window width. The PLA catch grows from the upward face during printing and needs no underside support. Slicer inspection is still needed to confirm the roof and ramp toolpaths with your profile.

## Nominal fit dimensions

- Rail remains 7.00 mm thick. Shoe channel is 7.50 mm wide: 0.25 mm clearance per face.
- Catch spans x = 9–19 mm from the outer corner; it rises 2.2 mm beyond the PLA face.
- TPU window wall is 1.8 mm thick; its inner face is at z = 7.25 mm.
- Passing the catch therefore requires up to 9.2 − 7.25 = **1.95 mm local outward displacement**. This is displacement, not a measured strain or installation-force prediction. The constrained TPU wall bends and stretches nonlinearly.
- Sole nominal contact with PLA is 28 × 7 = 196 mm² at each foot; actual floor pressure depends on load, sole deformation and the printed surface.
- Existing top tabs remain **7 × 22 mm, 7 mm engagement**, centers 39 and 111 mm. The historical **7.10 × 22.10 mm socket decision is preserved**. Its PLA/PLA fit does not calibrate TPU clearances.

## Geometry evidence

Checks use Manifold3D solid booleans plus Trimesh STL topology checks; the native SCAD was also compiled independently in OpenSCAD 2021.01 and compared with the generated solids. STL exports were reloaded and checked.

- V5 support: one watertight connected body, 80.1749 cm³.
- Modified reference support: one watertight connected body, 80.4191 cm³, 150 × 241 × 9.2 mm envelope. Original V5 material removed: **0 mm³**. Two catches add 244.2 mm³ (0.2442 cm³), about 0.30 g PLA at an assumed 1.24 g/cm³, or 0.30% added solid volume.
- PLA coupon: one watertight connected body, 3.8213 cm³, about 4.74 g fully solid PLA at 1.24 g/cm³.
- TPU foot: one watertight connected body, 1.8670 cm³, about 2.24 g fully solid TPU at an assumed 1.20 g/cm³. Use your spool density for a better estimate.
- Zero seated solid overlap for the coupon/foot, full support/left foot, full support/reflected right foot, and foot/foot pairs. The rail underside and sole touch intentionally; lateral assembly gaps are 0.25 mm nominal.
- Translating the seated shoe down 1 mm produces 13.5 mm³ collision with the catch. Translations of ±1 mm along the rail and ±1 mm across it also collide with the support. These checks demonstrate obstructions to straight rigid translation, **not** a measured retention force or proof against every combined rotation/peeling path.
- A rigid insertion sweep intentionally intersects the catch. The wall must flex during assembly; this is not a collision-free rigid sliding joint.
- Both support positions were transformed into the original V3 assembly coordinates. Their tab locations align with the nominal sockets, and solid top/support overlap is zero. This does not establish functional socket walls or validate the top structure.
- Both coupons fit easily inside the stated 256 × 256 mm bed. The reference support's 150 × 241 mm flat footprint fits the nominal bed, leaving only 15 mm total in its long direction before brims and printer exclusions.

No FEA, strength certification, fatigue test, floor-grip test or printer-specific slicing was performed. Filament masses above are solid-volume estimates, not slicer predictions.

## Inherited issues found during inspection

**Height:** V5 reaches 241 mm from bare rail bottom to tab top. The V3 platform is positioned with its top at the same height. Adding this sole yields **243 mm uncompressed overall height**, not 241 mm. This trial deliberately leaves V5's structural height and calibrated engagement unchanged. After foot fit succeeds, reconcile nominal overall height with the top. One possible later revision is reducing support body height by the sole allowance while retaining 7 mm engagement; that would require new brace/junction and assembly validation. Actual loaded height also depends on TPU compression.

**V3 top:** the supplied STL is watertight but has **five disconnected bodies: the platform and four separate socket bosses**. Each boss ends at about z = −0.01 mm; none is joined to the platform. Its lightening cuts and boss/socket region need inspection and repair before a full top print. Watertightness alone is insufficient. This inherited top is not modified or endorsed by the present connector trial.

**Historical tolerance coupon:** the supplied mesh reports non-watertight geometry and 24 components under the current parser. This does not negate the reported physical fit experiment. The selected tab/socket fit is retained; re-export/repair that mesh if it is needed again.

**Handedness:** the delivered test foot is for the illustrated corner. The opposite corner uses a reflected shoe. Reflection was included in the assembly checks, but a duplicate production batch has not been released. Do not assume four identical end-stop shoes fit all corners.

## Low-waste print and test sequence

1. Import each test STL separately into Bambu Studio with the correct material profile. Confirm millimetres and the dimensions above. For an assumed 0.4 mm nozzle, a 0.20 mm layer height and about four walls are a reasonable first coupon setup. Use your already-working PLA and TPU 95A profiles; no unverified temperature or speed is prescribed here. A solid TPU foot makes this small retention trial repeatable; confirm gap fill produces continuous 1.8 mm walls. Keep settings consistent for future comparisons.
2. Inspect sliced catch layers for continuous attachment, and the window roof for a clean 2 mm final bridge. Check the sole is solid and the end stop remains present. Print supports are not intended. Report predicted grams/time before scaling up; do not print a full support yet.
3. Print one PLA coupon and one TPU foot. Check for elephant-foot bulges, strings in the window, and cracks/delamination at the catch. Remove strings, but do not sand away the catch or window to force a fit: that would hide the tolerance result.
4. Align the corner with the end stop, the window with the raised catch, and the sole under the rail. Flex the window wall outward with a finger and seat the rail against the sole. The catch should appear in the window and the wall should return toward its relaxed position. Do not force the PLA if the shoe will not seat by hand.
5. Hold the PLA coupon and gently tug the TPU toward the floor and in both directions along the rail. It should remain captured without deliberate peeling. Inspect seating and end play; the designed clearance means some small free movement is expected.
6. Peel the window wall outward until it clears the catch, then remove the foot. Repeat 10 installation/removal cycles. Inspect window edges for tearing, permanent stretch and the PLA catch for whitening or cracking. Note whether retention weakens.
7. Apply hand compression through the coupon on the intended floor, then do 20 short back-and-forth strokes. Check for migration, rolling of the shoe, exposed PLA touching the floor and visible marks. This is a screening test, not a substitute for full-assembly testing.

Return: whether it seated by hand; tightness/looseness; whether it stayed captured during gentle tugging and dragging; whether intentional peeling worked; any damage after cycling; slicer grams/time; and your TPU brand/profile. If possible, include a close photo of the seated window. The first adjustment should change one fit variable at a time—for example clearance—with the PLA corner and print settings held constant. Do not print multiple tolerance variants up front.

Manufacturer background: TPU print preparation and adhesion vary with the material and surface; consult the filament maker's instructions. The [Prusament TPU 95A material guide](https://help.prusa3d.com/article/prusament-tpu-95a-material-guide_899653) is a useful example, not evidence that your particular TPU will have the same snap response.

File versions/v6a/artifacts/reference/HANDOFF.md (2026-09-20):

# Modular Backpack Footrest — Codex Handoff

## Goal
Design a compact, flat-pack, tool-less 3D-printed office footrest inspired by an IKEA kids bathroom stool, but optimized to fit in a backpack and assemble at the office.

Target use: seated footrest only. Not intended to be stood on or used as a step stool.

## User / Printer Constraints
- Printer: Bambu Lab A1, 256 x 256 mm bed.
- Main structural material: PLA.
- TPU 95A is now available for replaceable non-slip feet.
- User strongly prefers low filament waste and wants engineering decisions explained as the design evolves.
- Design should look intentional/product-like, not like a bulky hobby print.
- Tool-less assembly; avoid screws/nuts/bolts/glue where practical.

## Target Dimensions
- Finished height: 9.5 in = 241 mm.
- Current top target: about 230 x 170 mm.
- Flat-pack parts must fit A1 bed individually.

## Physically Calibrated Tab/Slot Fit
This is the most important validated parameter.

Existing support tab nominal cross-section:
- 7.00 mm thick
- 22.00 mm wide
- 7.00 mm insertion depth

Physical clearance test used 7 mm-deep sockets:
- I = 7.10 x 22.10 mm (+0.10 mm total clearance)
- II = 7.20 x 22.20 mm (+0.20 mm total clearance)
- III = 7.30 x 22.30 mm (+0.30 mm total clearance)
- Earlier 7.50 x 22.50 mm (+0.50 total) was visibly too loose.

User test result:
- III still too wobbly.
- I and II had similarly little true joint wobble.
- I was slightly harder to dislodge and felt slightly more stable.

DECISION: use 7.00 x 22.00 mm tabs into 7.10 x 22.10 mm sockets.
Keep 7 mm engagement. Do NOT increase depth unless future full-scale geometry reveals actual angular play. The previous idea of 12-15 mm engagement was abandoned because the observed coupon movement was mostly the tiny coupon tipping off its edge, not the joint rocking inside the socket.

## Current Structural Direction
The side support should be a lightweight truss/frame rather than a solid panel or honeycomb-filled slab.

Engineering reasoning:
- Main deformation mode is racking/shear of a tall rectangular support.
- Triangulation is more material-efficient than generic honeycomb for this specific load path.
- Keep material around the perimeter and at joints; remove material from low-value interior regions.
- Avoid long skinny members that become buckling-prone.
- Local gussets/junction reinforcement are preferable to making every member thick.

Current V5 support geometry:
- Overall support part envelope: 150 x 241 x 7 mm.
- Structural body height: about 234 mm + 7 mm tabs.
- Perimeter frame width: 10 mm.
- X-braces: 8 mm.
- Small local junction pads/gussets at brace/frame intersections.
- Two top tabs: 22 x 7 x 7 mm, centered approximately at 39 mm and 111 mm across the support width.
- Mesh was validated as one connected, watertight body.
- Raw solid geometry volume: ~80.17 cm^3, roughly 99 g PLA-equivalent if fully solid. Actual slicer usage will depend on walls/infill.

Previous V4 was 12 mm perimeter / 10 mm X-braces and was ~95 cm^3. V5 reduced raw geometry volume by ~16%.

DO NOT blindly shrink rails further. If optimizing weight, reason about buckling, member slenderness, joint loads, and print orientation.

## Top Platform
Current top concept/source is from V3 and is not yet final relative to the latest V5 support.

V3 concept:
- ~230 x 170 mm top.
- Lightweight underside pockets/ribs rather than a thick solid plate.
- Four calibrated sockets for the two side supports.
- Local bosses around socket locations so the full 7 mm engagement is available without making the whole top 7 mm thick.

Important: before printing a full top, reconcile the top socket positions with the final V5/V6 support geometry and validate assembly computationally.

## TPU Feet — Current State
Decision: use small replaceable TPU 95A feet for grip and floor protection.

Engineering philosophy:
- PLA carries structural load.
- TPU handles friction/compliance.
- TPU should be a replaceable wear item, not a structural requirement.

A V5 TPU slip-on shoe exists in the attached files, but DO NOT treat it as final.
Issue discovered: the V5 PLA support has no dedicated connector/retention geometry; the TPU shoe only friction-grips the bottom rail.

NEXT DESIGN CHANGE REQUIRED:
Add an intentional mechanical retention feature to the bottom corners of the PLA support and redesign the TPU foot to mate with it. Preferred concepts:
- shallow dovetail,
- T-slot / mushroom-style slide feature,
- small captured snap geometry suitable for TPU 95A.

Requirements for TPU foot connector:
- should not materially weaken the 10 mm bottom rail,
- localized near each bottom corner,
- easy to replace,
- no glue,
- mechanically retained so it does not walk off when the footrest is moved,
- keep each TPU foot only a few grams.

Do NOT print the existing TPU foot before redesigning this interface.

## Validation Workflow — Important
The user wants a disciplined, low-waste engineering workflow.

For every major revision:
1. Validate dimensions against A1 bed and 241 mm assembled height.
2. Validate tab/slot dimensions use the physically tested fit: 7.00 x 22.00 tab, 7.10 x 22.10 slot, 7 mm engagement.
3. Assemble parts computationally and check positions/alignment.
4. Check meshes are watertight.
5. Check connected-component count: a structural part should be one connected body. This matters because an earlier diagonal brace only appeared connected but exported as a separate shell.
6. Check for unintended intersections or gaps at brace/frame/tab junctions.
7. Calculate raw mesh volume and approximate material mass.
8. Prefer small coupons for any new joint/TPU retention feature before committing a large print.
9. Slice before printing large structural parts and inspect predicted grams/time.
10. User prefers printing one representative part first before committing to duplicates.

## Known Failure / Lessons Learned
- Earlier support brace visually approached the perimeter but was actually a disconnected mesh. Always check component count after STL export.
- Earlier clearance of +0.50 mm total was too loose.
- Do not change two experimental variables at once; e.g. clearance and engagement depth should not be altered together when calibrating.
- The user is actively checking geometry and will notice questionable interfaces. Explain why each change is mechanically justified.

## Suggested Next Steps
1. Modify the V5 support bottom corners to include a shallow, structurally safe TPU-foot retention feature.
2. Design one tiny TPU 95A test foot/coupon around that connector.
3. Validate the connector mechanically/geometrically before changing anything else.
4. Reconcile/update the top platform against the finalized support/tab layout.
5. Build an assembled reference model and run component/interference checks.
6. Compute actual volume/material estimates.
7. Ask user to slice one support in Bambu Studio and report grams/time before printing it.
8. Only then decide whether the 10 mm perimeter / 8 mm brace can be reduced further.

## Files Included
- flatpack_footrest_v5_light_support.scad — current support source, best structural starting point.
- flatpack_footrest_v5_light_support.stl — current support export.
- flatpack_footrest_v3.scad — older full design source containing top/assembly concepts; use carefully because support has evolved since then.
- flatpack_footrest_v3_top.stl — current top reference, not final.
- footrest_tolerance_coupon_v6_7mm_sockets_only.stl — physical calibration coupon used to choose +0.10 mm clearance.
- flatpack_footrest_v5_tpu_foot.scad / .stl — obsolete friction-fit TPU foot concept; reference only, needs connector redesign.

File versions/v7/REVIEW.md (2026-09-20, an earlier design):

# V7 ribbed 240 mm top and rear X brace

Stage: `v7`. Previous recorded stage: `v6a`. Retrospectively documented 2026-09-20.

## Change and reason

Chose 240 x 170 mm one-piece top for A1 bed rather than wider split platform. Added connected rib/boss top, shortened support for nominal 241 mm height, rail stiffeners and rear X brace. Rear joint repeated a tight 7 x 22 x 7 interface. User measured heel spread about 12 inches and seated load about 25.6 lb; 200 N remained an unproven check target.

## Recorded CAD/analysis evidence

Recorded topology, exact tab/socket and rail checks, assembly/insertion booleans, orientation review, rebuild checks and idealized structural screens. These screens were not measured full-frame stiffness or strength.

## User-reported physical evidence

Top and rear coupons fit with effort. Full rear brace/support slid in then tightened/snapped; could not be removed by hand. Pulling later broke the rear key/tab inside support; user discarded both. Photo/orientation review did not identify reversed assembly as the cause. Reported slicer masses: rear 26 g, supports 54 g each, top 161.41 g.

## Outcome and next question

Rear connection failed packability/removal. Top and TPU interfaces subsequently retained. Do not reuse tight rear fit; geometry validity did not establish removability.

## Provenance caveat

Copied artifacts and archives are preserved as found. Some source READMEs contain later annotations or stale release instructions. This review and repository STATUS take precedence for interpreting current experimental status. No CAD or physical tests were rerun during this history import.

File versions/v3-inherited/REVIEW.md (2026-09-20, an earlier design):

# Inherited V3 top and assembly concept

Stage: `v3-inherited`. Previous recorded stage: `supplied handoff`. Retrospectively documented 2026-09-20.

## Change and reason

Imported the older top/assembly reference supplied with the handoff. Approximate 230 x 170 mm top; not reconciled to the latest support.

## Recorded CAD/analysis evidence

Later V6A inspection reported five disconnected top bodies (platform plus four socket bosses), despite watertightness. That finding belongs to the later inspection, not an original V3 test.

## User-reported physical evidence

No full V3 top test result is available in this conversation.

## Outcome and next question

Reference only. Required connected socket bosses, support reconciliation and height review. Handoff also mentions unavailable V4 and earlier disconnected-brace failures.

## Provenance caveat

Copied artifacts and archives are preserved as found. Some source READMEs contain later annotations or stale release instructions. This review and repository STATUS take precedence for interpreting current experimental status. No CAD or physical tests were rerun during this history import.

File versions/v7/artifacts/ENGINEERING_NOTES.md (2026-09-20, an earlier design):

# V7 structural reasoning and limits

## Load assumptions

Measured seated load reported by the user: 25.6 lbf ≈ 113.9 N. Agreed vertical check load: 200 N total, about 1.76 times that measurement. This ratio is an allowance on the observed load, not a computed strength safety factor. A separate 20 N horizontal load is an illustrative racking screen chosen for this design pass; it is not a measured user force or a certified requirement.

This remains a seated footrest. No load rating is assigned. PLA brand, print properties, creep and environmental temperature have not been measured for this build.

## Top load path and approximate calculation

The 2.4 mm skin spreads local heel pressure into the grid. Three 5 mm-wide left-right ribs have 16 mm total section depth including the skin. Five 3.6 mm-wide transverse ribs and a 3 mm-wide perimeter reach 10 mm total depth. Bosses are joined directly to the skin and ribs. The 7 mm-deep sockets lie entirely within those bosses; they do not cut through a lightening pocket. Nominal socket side walls are 3.45 mm thick and end walls are 4.95 mm thick.

A small linear beam-grillage model represents skin strips and ribs. At each node it has vertical translation and two rotations. Each member includes Euler–Bernoulli bending and approximate rectangular-section torsion; Poisson ratio is assumed 0.35. Vertical support points are placed at x=22/218 and y=49/85/121, where the actual shoulders/main rib contacts support the deck. Rotations at those points remain free. The solution balances the 200 N load with 200 N of reaction. A separate simply-supported beam check matches the classical center-load deflection to numerical precision.

Calculated deflections for assumed effective E=1500–2500 MPa:

- 200 N over a 40 × 40 mm central patch: approximately **1.11–1.85 mm**.
- Two 100 N, 40 × 40 mm heel patches centered at x=60 and 180 mm, y=85 mm: approximately **0.61–1.02 mm** maximum.
- 200 N at an ideal mathematical center point: approximately **1.29–2.14 mm**; the highest model nominal beam stress is about **13.5 MPa**.
- One offset 200 N patch centered at x=60, y=55 mm: approximately **1.26–2.11 mm**. This case gives very uneven support reactions and needs physical stability testing.

These are screening results, not verified full-assembly predictions. The model has ideal connections and solid sections; it omits local plate deformation between ribs, shear-lag, stress concentrations at pockets/joints, orthotropic print behavior, creep, support deflection and foot compression. Its strip/torsion idealization is approximate and has not been correlated with a printed top. The modulus interval is a sensitivity assumption, not a guaranteed material bound. No allowable stress or material-based safety factor has been established. The numbers justify proceeding to a prototype, not claiming proof of capacity.

For context only, [Bambu's filament guide](https://cdn1.bambulab.com/filament/filament-guide/250123/filament-guide-en.pdf) lists 2750 MPa for PLA XY bending modulus. That is not substituted as the actual modulus of the user's print. Beam equations follow conventional elastic beam theory; see the [US Air Force stress-analysis manual, hosted by Engineering Library](https://engineeringlibrary.org/reference/simple-beam-bending-air-force-stress-manual).

## Why add a rear brace?

The original X lies in each side frame's plane. It is useful against fore-aft racking, but it does not triangulate the space between the two side frames. Tightening the top fit does not remove the tall frames' weak-axis flexibility.

An idealized out-of-plane beam model of a bare V5-style frame, with its bottom corners fully fixed, predicts large lateral compliance at only 10 N per side panel. The resulting displacement is too large for the model's small-deflection assumptions to remain reliable; it is a warning about the load path, not a literal displacement prediction. This model is explicitly for the original unflanged, unbraced frame, not final V7.

V7 adds a rear X in the across-width plane. Its 8 × 6 mm diagonals are about 253 mm between attachment centers and convert much of a sideways push into axial tension/compression. Under an ideal 20 N horizontal load split between both diagonals, each has approximately 12.9 N axial force (0.27 MPa nominal axial stress). An ideal full-length pinned compression-member Euler screen gives roughly 33–56 N for the assumed E range, without crediting the fused crossing as a midspan brace. Imperfections and printing can reduce that value. It is not a buckling proof for the full assembly.

Ideal axial stretch of those two brace members would contribute only about 0.04–0.06 mm displacement. **This is not the assembly's predicted sway.** Socket clearance, end-block deformation, short unbraced frame extensions, foot compliance, possible joint withdrawal and torsion can dominate. Physical lateral testing is still necessary. The brace is retained by press fit; no positive anti-withdrawal latch has been claimed.

Raised 6 × 3 mm flanges along the support rails increase the local solid section's weak-axis second moment from about 286 to 657 mm⁴, roughly 2.3 times. This comparison excludes taper/end effects and does not establish the panel's global buckling capacity. The original 10 × 7 mm rail remains underneath the addition.

## Stability and unverified behavior

The nominal flat-foot contact envelope is x=16.45–223.55 mm and y=8.2–161.8 mm. This defines an outer support polygon, not a guarantee that the resultant load always stays inside it. Heel position, horizontal push, floor friction and TPU deformation affect sliding/tipping. An empty lightweight footrest is particularly easy to move or tip. No friction coefficient or tipping load is asserted.

The 241 mm height is unloaded nominal geometry. TPU compression, print variation and joint seating affect measured height. Bed fit is based on object envelopes; brims and printer exclusions still require slicer inspection.

Full-assembly strength, global buckling, fatigue, long-term creep, accidental impacts and handling retention are unresolved until physical testing. The conservative next step is the two small joint pairs, followed by slicer review and one representative support—not printing all duplicates at once.

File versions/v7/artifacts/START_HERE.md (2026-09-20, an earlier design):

# V7 — one-piece top and braced flat-pack footrest

**Status: geometry-checked prototype. Print the two PLA joint pairs first.**
200 N is the agreed provisional vertical design/check load, not a tested working-load rating. The user's measured seated load was approximately 25.6 lb = 113.9 N. No standing/step-stool use is intended.

## What changed

The one-piece top is 240 × 170 mm, with a 2.4 mm skin, three 5 mm-wide main ribs reaching 16 mm below the top, smaller cross-ribs, a 10 mm-deep perimeter and 6 mm corner radii. Four blind socket bosses are part of that same solid body. No lightening cut crosses their walls. The calibrated top connection stays 7.00 × 22.00 mm into 7.10 × 22.10 mm, with 7.00 mm straight engagement.

Support centerlines are 22 and 218 mm across the top: 196 mm apart, with 22 mm centerline-to-edge overhangs. The top sits on support shoulders, not on a disconnected boss. New guides extend 8 mm alongside the 10 mm-high upper rail with a 7.4 mm gap (0.2 mm per face). They spread joint bearing over a longer region without changing the tab engagement. Guide fit is provisional.

The support body is shortened from 234 to 223 mm, and brace endpoints follow the new height. The height stack is 2 mm sole + 223 mm body + 16 mm deck = **241 mm nominal, before TPU compression**. Tabs extend 7 mm into the 16 mm deck, leaving 9 mm above their ends. Printed support height including tabs is 230 mm.

The V5 10 mm perimeter rails and 8 mm diagonal widths are retained. Added 6 × 3 mm flanges along the tall rails help resist bending across their thickness. The flanges taper out before the foot and top guide regions. No bottom-rail material is removed.

The out-of-plane frame screen exposed a weakness that top guides alone cannot solve. A removable rear X-brace now ties the supports together. It has 8 × 6 mm diagonal members, four 7 × 22 × 7 mm tabs and no glue or hardware. Added blocks behind each rear support rail receive those tabs; their socket cuts lie outside the original rail. The brace is retained by the trial press fit, not a positive latch. Its handling retention and four-point registration must be checked in the physical assembly.

The rear panel makes overall assembled depth **174 mm**, although the top remains 170 mm. All parts remain flat-packable.

**V6A foot geometry and catches are unchanged.** The user has already passed its seating, retention, cycling and dragging tests. Do not reprint another foot coupon.

## Print first: four small PLA pieces, two tests

All STLs are in millimetres and already in their intended print orientations. Keep those orientations: rotating a coupon can change the fit/bridge behavior it is supposed to test.

1. `PRINT_FIRST_top_socket_coupon.stl` — approximately 11.2 g solid PLA.
2. `PRINT_FIRST_top_tab_coupon.stl` — approximately 4.1 g solid PLA.
3. `PRINT_FIRST_brace_socket_coupon.stl` — approximately 5.0 g solid PLA.
4. `PRINT_FIRST_brace_tab_coupon.stl` — approximately 6.7 g solid PLA.

The four pieces can share one PLA plate, without material changes or a prime tower. For the lowest commitment, print the top pair first (about 15.3 g), then the brace pair (about 11.7 g). These are solid-volume estimates at 1.24 g/cm³, not slicer predictions; purge, brim and actual infill change usage.

For an assumed 0.4 mm nozzle, start with your proven PLA profile, 0.20 mm layers, six walls, six top and six bottom layers, and 20–30% infill. Use the same settings/material for the eventual matching parts. Six walls are intended to make the narrow ribs and brace members largely solid; inspect the actual toolpaths because line width changes that result. These settings are a starting point, not a validated print recipe.

Supports are not intended. The **brace socket has a 22.1 mm roof bridge**; inspect that bridge in the slicer and the printed coupon. Layer quantization also affects its 7.1 mm opening because that dimension lies through the support's print thickness. Do not enlarge or sand the opening before reporting whether it fits. Remove loose strings only. If the roof sags and obstructs insertion, stop and report it; that is precisely why this coupon comes before a full support.

### Top joint test

Insert the male tab into the socket between the two guide cheeks, as shown in `V7_coupon_assemblies.png`. The tab should enter fully by hand and the shoulder should seat against the boss underside. The guide cheeks should straddle the 7 mm-thick body without jamming; slight guide clearance is intended. Check for obvious side-to-side rocking, then assemble/disassemble 10 times. Report tightness, full seating, rocking and any whitening/cracking. This checks fit and local handling, not the top's bending capacity.

### Rear-brace joint test

Insert the projecting tab into the side opening of the socket block until its pad seats against the block's mouth. It should engage 7 mm by hand, have little transverse play, resist falling out during ordinary handling and be removable without tools. Repeat 10 cycles. Report any bridge sag, scraping, looseness or damage. The nominal cross-section matches the earlier calibrated joint, but its print orientation is different; it is not assumed calibrated merely because the numbers match.

No test here establishes a full 200 N capacity. Report these results and slicer grams/time before committing the large parts.

## Full prototype files — after coupon results and slicer review

- `V7_top_PROTOTYPE.stl`: print 1, 240 × 170 × 24 mm. Smooth foot-contact surface faces the bed; ribs and guides grow upward. About 252 g solid PLA.
- `V7_support_PROTOTYPE.stl`: eventually 2 identical parts, 158 × 230 × 14.1 mm. Flat original face on bed; catches, stiffeners and socket blocks upward. About 111.5 g solid PLA each. Print one representative support first to inspect rail continuity, upper tabs, brace sockets and the existing TPU foot fit.
- `V7_rear_brace_PROTOTYPE.stl`: eventually 1, 220 × 190 × 13 mm. Flat X on bed, tabs upward. About 52.7 g solid PLA.
- `V6A_unchanged_foot_left.stl`: 2 total for the complete assembly; your successful test shoe can count as one.
- `V6A_mirrored_foot_right.stl`: 2 total for opposite corners. About 2.24 g solid TPU each at assumed density 1.20 g/cm³. Print separately from PLA, sole down, with your tested TPU settings.

The theoretical fully solid total is about **537 g**, excluding coupons, brims and purge. This is not weight-optimized further: the extra rear brace and local rail stiffeners address a structural weakness. Actual slicer usage must be reviewed before deciding whether and where to reduce material.

The top leaves only 8 mm nominal bed margin per side along its 240 mm direction; center it and check any brim and printer exclusion areas. Do not scale parts to make a brim fit. Other pieces have more margin.

## Assembly order

1. Attach the tested TPU shoes to the support corners. Each support takes one left and one mirrored right shoe.
2. Place the top upside down on a protected surface. Insert both supports into the top. Their added rear socket blocks must face the same rear edge, and their raised printing faces must point toward the same global side, as in the reference model. Do not mirror one support: the brace block thickness is intentionally asymmetric.
3. With both supports fully seated, align all four rear-brace tabs and slide the brace forward into their rear-facing sockets. Support the joint areas while seating; do not flex a diagonal to force a misaligned tab.
4. Turn upright and check that all soles contact the floor, all shoulders/pads remain seated, and there is no obvious rocking or loose brace. Refer to the assembly image or open `V7_assembly_REFERENCE.glb` in a compatible 3D viewer. This GLB is not a print file.

The coupons cannot establish four-socket registration, whole-frame stability or brace retention during handling. Those checks occur on the real assembly. Full assembly must still undergo a staged measured load/deflection check, lateral/handling check and sustained seated-use observation before treating the prototype as accepted. The next load-test details should be selected after the coupon results and actual slicer settings are known.

## Validation performed

OpenSCAD 2021.01 rendered the native source; Manifold3D and Trimesh then checked the exported solids. Every individual STL is watertight, has consistent winding and exactly one connected component. All fit within a 256 mm cube in their supplied orientation.

All 28 pairs in the eight-component assembly (top, two supports, rear brace, four feet) were checked for unintended intersection. Maximum overlap was numerical zero. Sampled insertion paths for the supports and rear brace also have no interference. Small deliberate over-insertion produces shoulder contact, confirming the intended stops exist.

The actual tab solids were compared with exact 7 × 22 × 7 mm boxes. All four top socket voids and their complete walls/roofs were checked with solid booleans. The top and brace coupon assemblies have zero unintended overlap. Foot geometry and catch projections were compared with V6A; their differences are numerical zero. The complete 150 × 10 × 7 mm bottom rail remains present.

See `geometry_checks.json` for measurements, checks and STL hashes, and `ENGINEERING_NOTES.md` for the structural model and its limitations. Geometry validity is not a strength certification.

## Source and reproducibility

`footrest_V7.scad` defaults to a colored assembly preview. Its `part` selector can export each part or coupon. The default dimensions are checked; editing dimensions requires rerunning validation and possibly updating the assembly transforms/model assumptions.

`build_and_validate.py` renders all individual parts using an installed OpenSCAD executable, validates them, and regenerates STL/GLB files. Install the packages in `requirements.txt` in a Python virtual environment, then run `python build_and_validate.py --openscad /path/to/OpenSCAD`. `structural_screen.py` reproduces the approximate beam calculations. `render_views.py` creates the mesh-derived pictures. Reference V6A meshes are supplied only for regression checks.

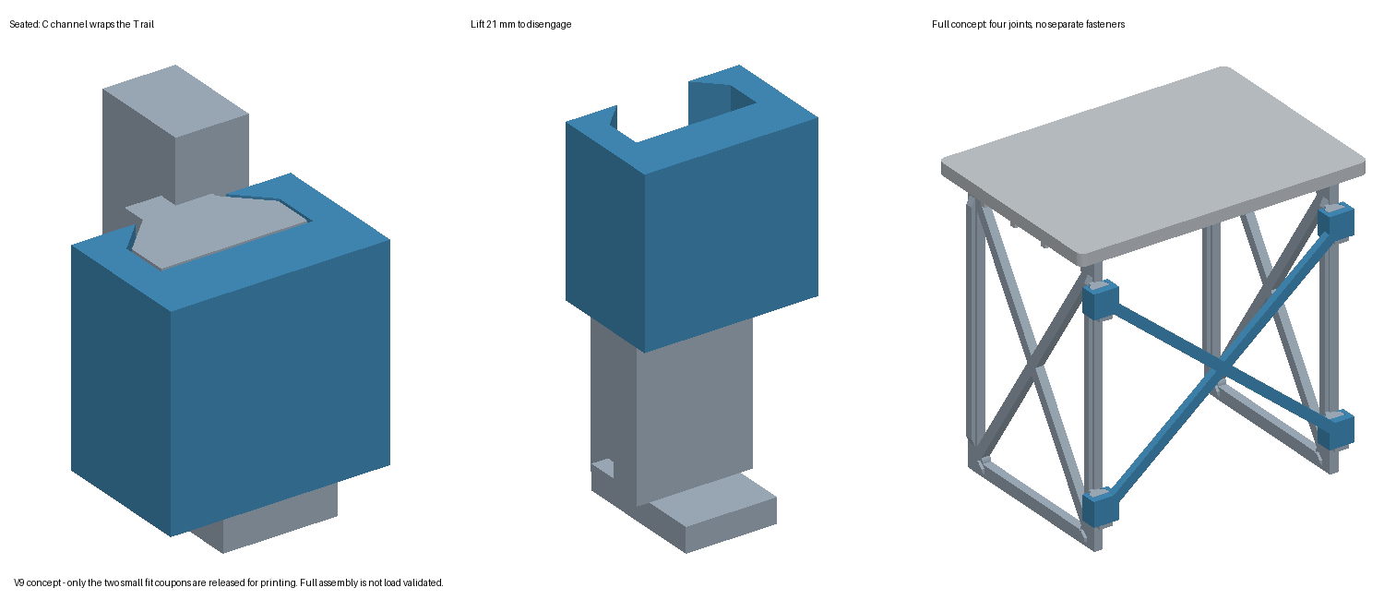
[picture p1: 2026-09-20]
versions/v9-trial/artifacts/V9_design.png

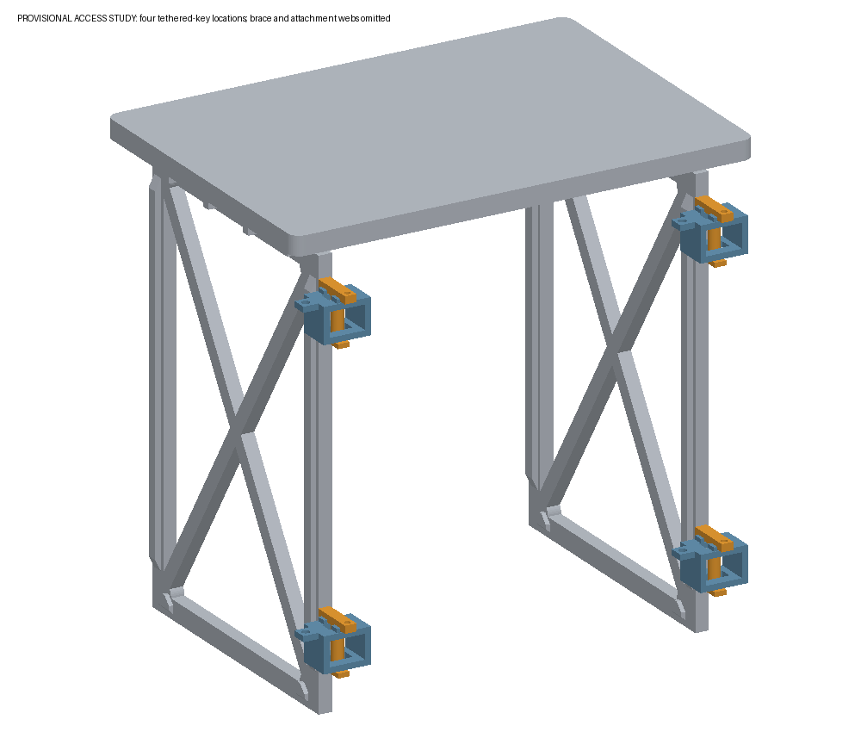
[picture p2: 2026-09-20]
versions/v8b/artifacts/V8B_access_study.png

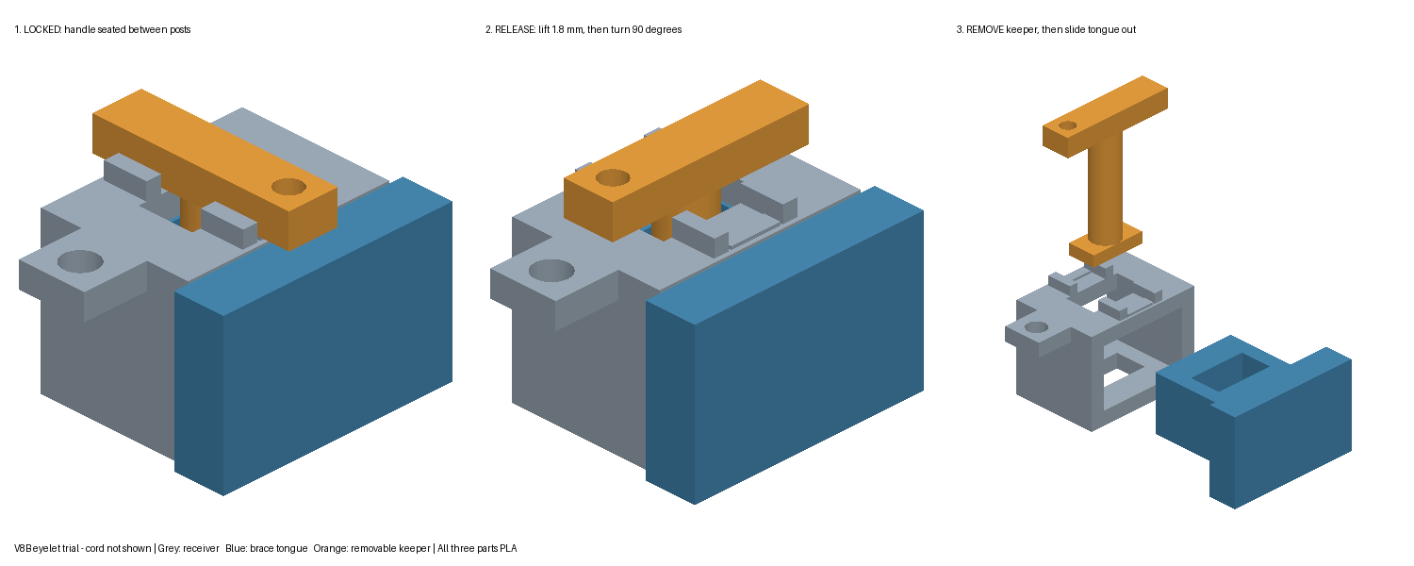
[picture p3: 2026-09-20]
versions/v8b/artifacts/V8B_release_sequence.png

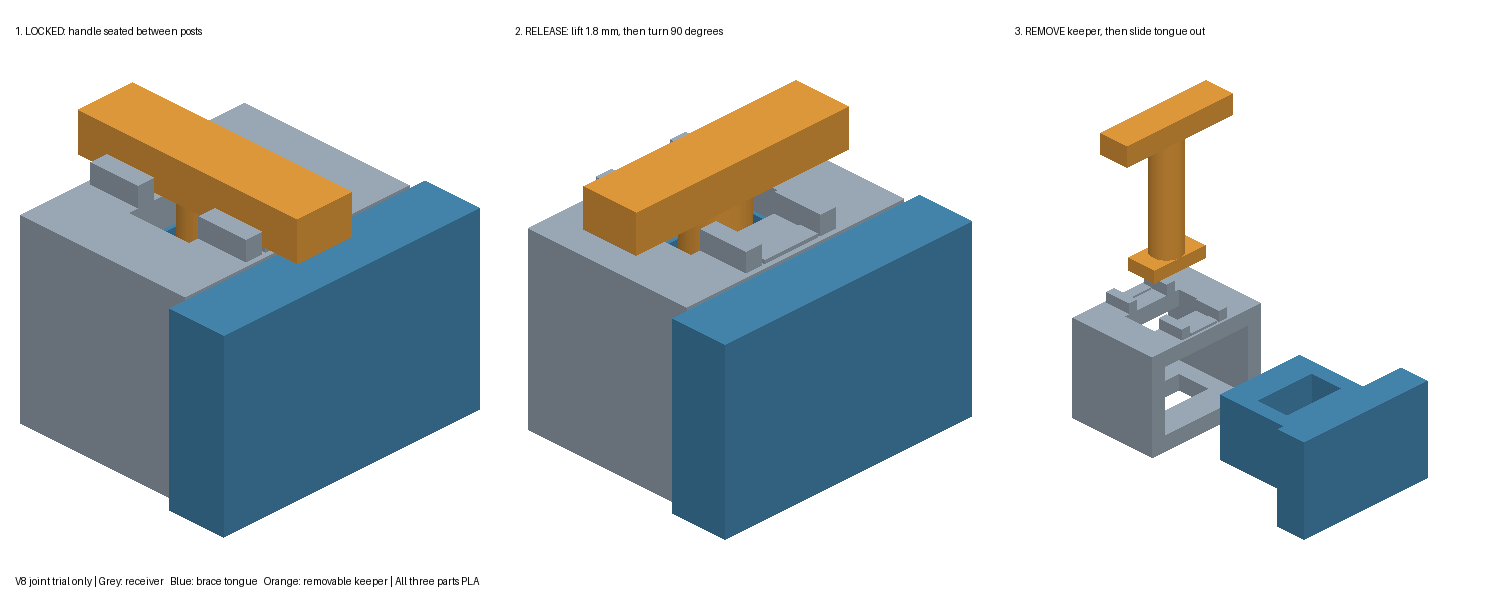
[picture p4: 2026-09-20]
versions/v8/artifacts/V8_release_sequence.png

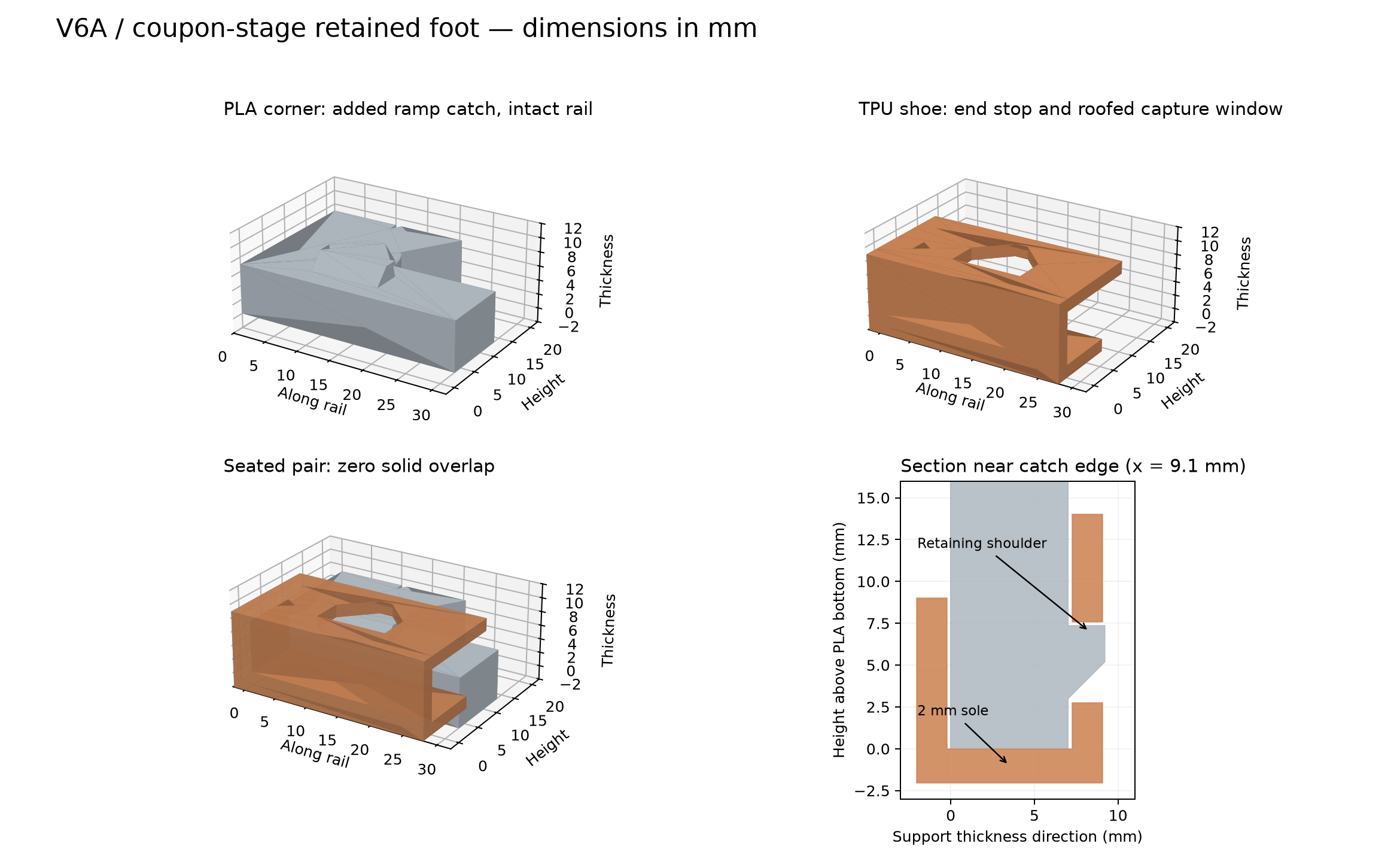
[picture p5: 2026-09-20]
versions/v6a/artifacts/V6A_interface_review.png

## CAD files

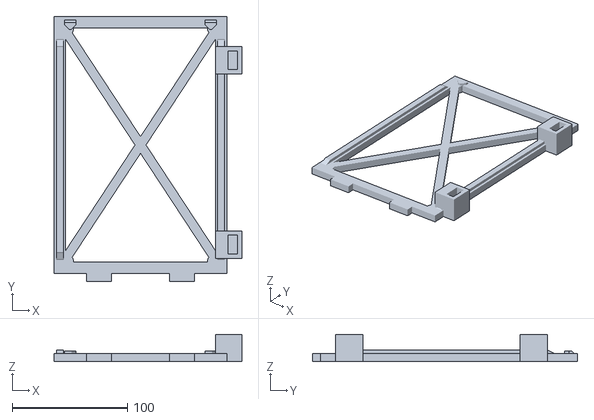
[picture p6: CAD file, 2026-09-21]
current/PLA/03_right_support_PRINT_1.stl
163.0 x 230.0 x 23.5

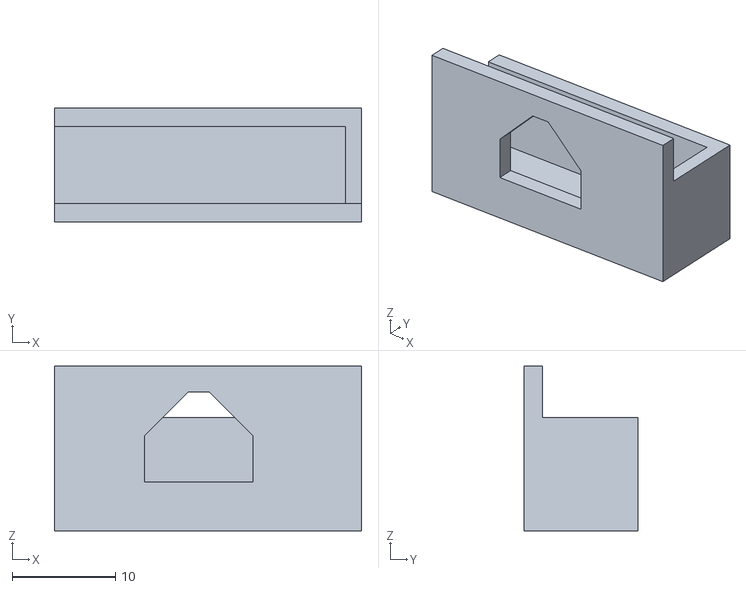
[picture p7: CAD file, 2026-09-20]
current/TPU95A/06_foot_B_PRINT_2.stl
29.8 x 11.1 x 16.0

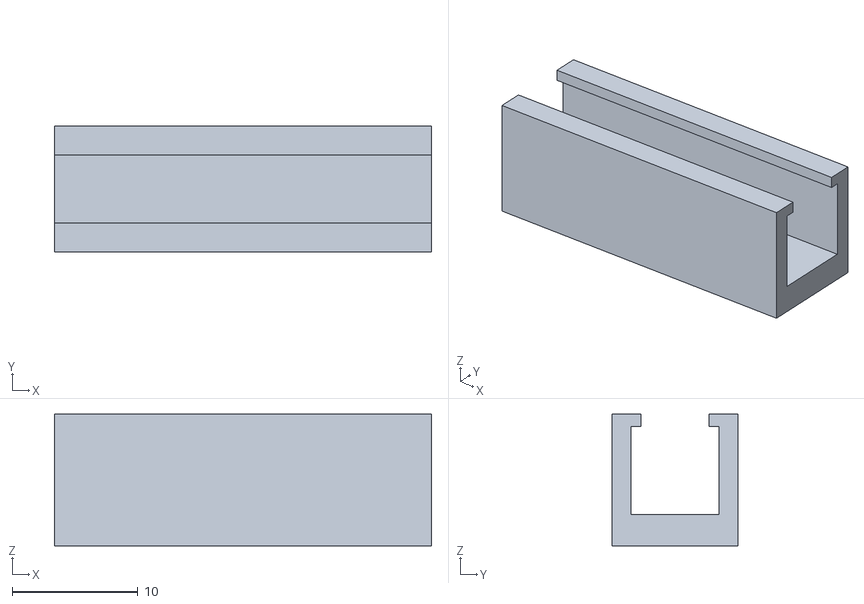
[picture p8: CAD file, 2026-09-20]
versions/v6a/artifacts/reference/flatpack_footrest_v5_tpu_foot.stl
30.0 x 10.0 x 10.5

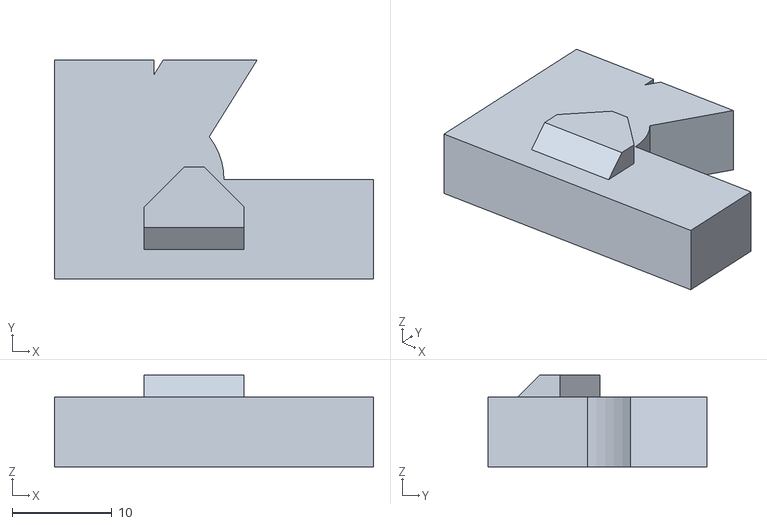
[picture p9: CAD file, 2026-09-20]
versions/v6a/artifacts/V6A_PLA_corner_coupon.stl
32.0 x 22.0 x 9.20

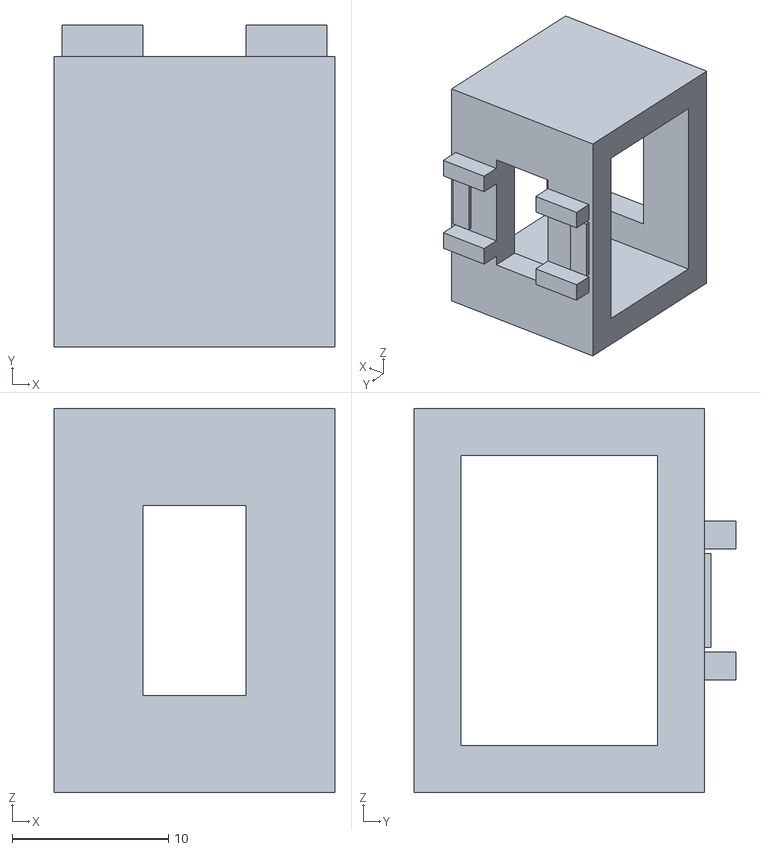
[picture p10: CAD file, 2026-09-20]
versions/v8/artifacts/V8_trial_receiver.stl
18.0 x 20.6 x 24.6

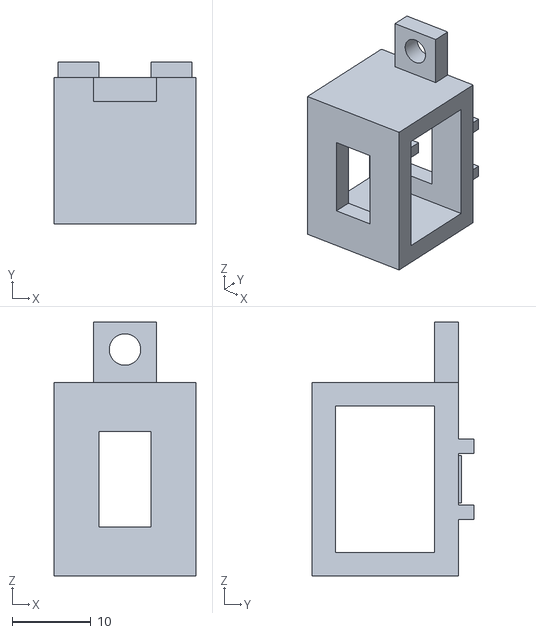
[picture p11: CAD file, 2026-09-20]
versions/v8b/artifacts/V8B_trial_receiver.stl
18.0 x 20.6 x 32.3

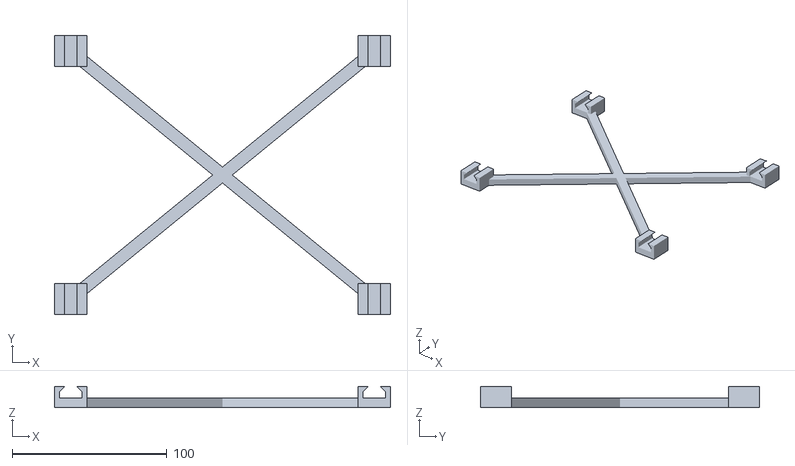
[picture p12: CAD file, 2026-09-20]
versions/v9-bracket-v2/artifacts/PRINT_V9_bracket_V2_0p15_PLA.stl
217.0 x 180.0 x 13.6

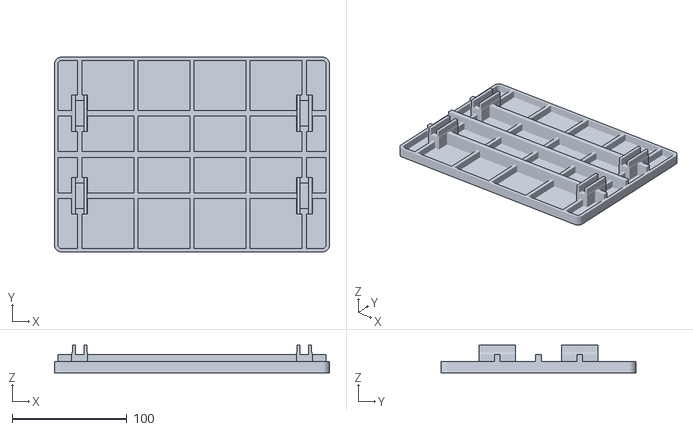
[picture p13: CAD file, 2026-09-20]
versions/v9-full/artifacts/reference/unchanged_top.stl
240.0 x 170.0 x 24.0

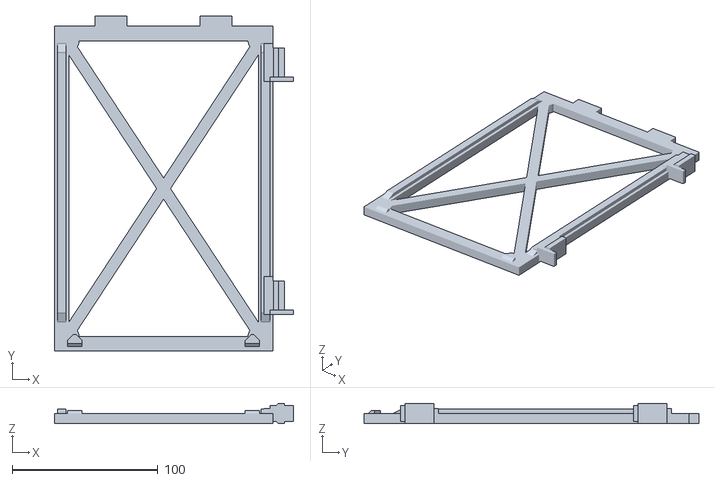
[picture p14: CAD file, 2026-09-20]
versions/v9-full/artifacts/V9_support_PLA_PROTOTYPE.stl
164.3 x 230.0 x 14.0

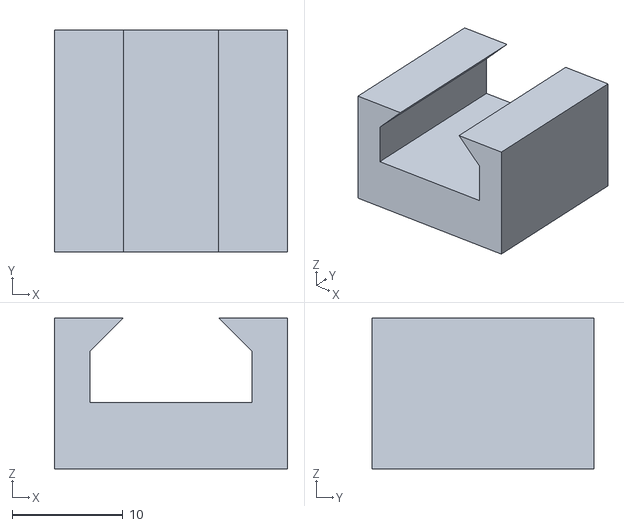
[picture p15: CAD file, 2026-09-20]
versions/v9-trial/artifacts/PRINT_FIRST_V9_channel_coupon.stl
21.0 x 20.0 x 13.6

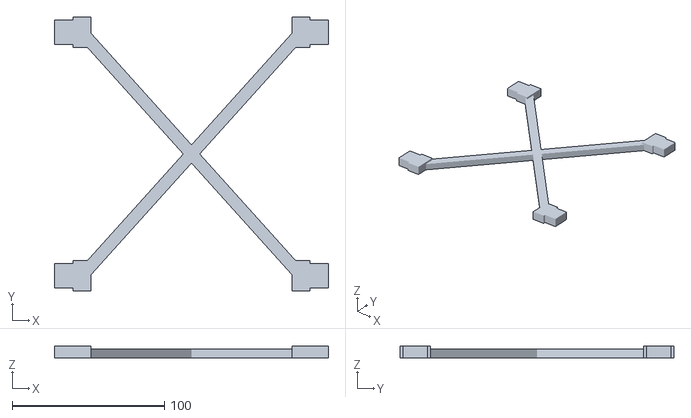
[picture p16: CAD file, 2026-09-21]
current/PLA/04_rear_brace_PRINT_1.stl
180.0 x 180.0 x 8.00

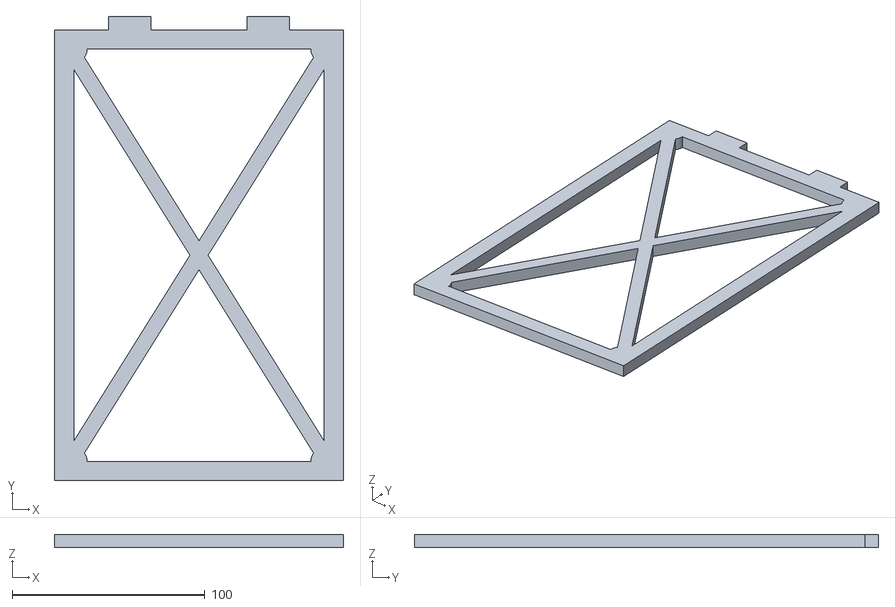
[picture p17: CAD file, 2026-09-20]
versions/v6a/artifacts/reference/flatpack_footrest_v5_light_support.stl
150.0 x 241.0 x 7.00

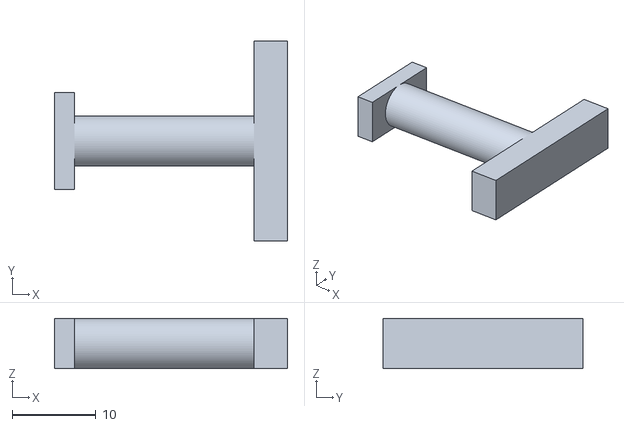
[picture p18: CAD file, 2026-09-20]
versions/v8/artifacts/V8_trial_keeper.stl
27.9 x 24.0 x 6.00

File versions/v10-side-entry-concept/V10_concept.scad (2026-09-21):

// V10 SIDE-ENTRY CONCEPT ONLY. No printable release or load rating.
use <reference/V7.scad>
part="assembly";
$fn=48;
module box(a,b){translate(a)cube(b-a);}
module left_world(){union(){
 place_support(22){support_core();rail_stiffeners();}
 for(z=[40,200])difference(){
  box([22,150,z-12],[42,173,z+12]);
  // Inward-facing blind pocket. Closed above and below, open toward center.
  box([28,160.85,z-8.15],[42.1,169.15,z+8.15]);
 }
}}
module right_world(){translate([240,0,0])mirror([1,0,0])left_world();}
module brace_world(){union(){
 for(z=[40,200]){
  box([30,161,z-8],[42.2,169,z+8]);
  box([42,161,z-10],[54,169,z+10]);
  box([197.8,161,z-8],[210,169,z+8]);
  box([186,161,z-10],[198,169,z+10]);
 }
 for(pair=[[[48,40],[192,200]],[[48,200],[192,40]]])
 hull()for(p=pair)translate([p[0],163,p[1]])rotate([-90,0,0])cylinder(d=8,h=6);
}}
if(part=="left")left_world();
else if(part=="right")right_world();
else if(part=="brace")brace_world();
else if(part=="top")place_top()top();
else {color("silver")place_top()top();color("slategray"){left_world();right_world();}color("steelblue")brace_world();}

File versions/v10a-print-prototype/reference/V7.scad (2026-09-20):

// V7: 240 x 170 mm one-piece ribbed platform, 241 mm nominal height.
// Seated-use prototype. 200 N is a design/check load, NOT a tested rating.
// Print joint coupons first. All printable selectors lie flat on z=0.
part="assembly"; // top, support, socket_coupon, tab_coupon, brace, brace_socket_coupon, brace_tab_coupon, foot_left, foot_right, assembly
$fn=48;
W=150; H=223; T=7; frame=10; brace=8;
tab_w=22; tab_h=7; tab_t=7; tab_centers=[39,111];
top_x=240; top_y=170; skin=2.4; deck_depth=16; rim_depth=10;
slot_t=7.10; slot_w=22.10; engagement=7;
support_x=[22,218]; support_y0=10; slot_y=[49,121];
sole=2; total_height=241;
guide_gap=7.4; guide_depth=8; boss_x=14; boss_y=32;
assert(abs(sole+H+deck_depth-total_height)<0.0001);
assert(slot_t==7.10 && slot_w==22.10 && engagement==7);
module cuboid(a,b){translate(a) cube(b-a);}
module xy_prism(points,z0,z1){translate([0,0,z0]) linear_extrude(z1-z0) polygon(points);}
module yz_prism(points,x0,x1){
 multmatrix([[0,0,1,x0],[1,0,0,0],[0,1,0,0],[0,0,0,1]])
 linear_extrude(x1-x0) polygon(points);
}
module beam2d(x1,y1,x2,y2,w){hull(){translate([x1,y1])circle(d=w);translate([x2,y2])circle(d=w);}}
module frame2d(){union(){
 square([W,frame]);translate([0,H-frame])square([W,frame]);
 translate([0,frame])square([frame,H-2*frame]);translate([W-frame,frame])square([frame,H-2*frame]);
 beam2d(frame-5,frame-5,W-frame+5,H-frame+5,brace);
 beam2d(W-frame+5,frame-5,frame-5,H-frame+5,brace);
 for(p=[[frame,frame],[W-frame,frame],[frame,H-frame],[W-frame,H-frame]])translate(p)circle(d=14);
}}
// V6A catch and foot dimensions remain unchanged after user's successful trial.
module catch_left(){intersection(){
 yz_prism([[3,6.8],[11.25,6.8],[11.25,9.2],[5.2,9.2],[3,7]],9,19);
 xy_prism([[9,3],[19,3],[19,7.25],[15,11.25],[13,11.25],[9,7.25]],6.7,10);
}}
module support_core(){union(){
 linear_extrude(T)frame2d();
 for(c=tab_centers)translate([c-tab_w/2,H,0])cube([tab_w,tab_h,tab_t]);
 catch_left();translate([W,0,0])mirror([1,0,0])catch_left();
}}
// Rear brace sockets are ADDED behind the rear rail (local u=150).
// Socket cross section repeats 7.10 x 22.10, insertion is 7 mm along u.
// Socket roof bridges 22.1 mm: inspect the brace coupon's sliced bridge.
brace_levels=[40,200];
module brace_socket_blocks(){for(h=brace_levels)difference(){
 cuboid([148,h-15,0],[158,h+15,14.1]);
 cuboid([151,h-11.05,3.5],[158.01,h+11.05,10.6]);
}}
module rail_stiffeners(){
 // Raised 6 x 3 mm flanges resist weak-axis bending/buckling of the tall rails.
 // Stop clear of the tested foot and the top shoulder guides; no rail cuts.
 for(u=[2,142])yz_prism([[20,6.8],[H-12,6.8],[H-12,7],[H-18,10],[26,10],[20,7]],u,u+6);
}
module support(){union(){support_core();brace_socket_blocks();rail_stiffeners();}}
module brace_socket_coupon(){translate([-145,-25,0])intersection(){support();cuboid([145,25,0],[158,55,14.1]);}}
// Rear panel prints flat, tab projections up. Assembly tabs point forward.
module rear_brace(){union(){
 linear_extrude(6)union(){
  for(x=[12,208])for(y=[15,175])translate([x-12,y-15])square([24,30]);
  beam2d(12,15,208,175,8);beam2d(12,175,208,15,8);
 }
 for(x=[12,208])for(y=[15,175])cuboid([x-3.5,y-11,5.8],[x+3.5,y+11,13]);
}}
module brace_tab_coupon(){intersection(){rear_brace();cuboid([0,0,0],[24,30,13]);}}
module place_brace(){translate([13.55,174,27])rotate([90,0,0])children();}
module rounded_rect(w,d,r){hull(){for(x=[r,w-r])for(y=[r,d-r])translate([x,y])circle(r=r);}}
module outline(){rounded_rect(top_x,top_y,6);}
module perimeter(){difference(){outline();translate([3,3])rounded_rect(top_x-6,top_y-6,3);}}
module guide(sx,cy){
 // Guides engage the shoulder/body with 0.2 mm per face, NOT extra tab depth.
 // Top frame is 10 mm high; guides extend 8 mm below its bearing shoulder.
 for(sign=[-1,1])translate([sx,cy,0])scale([sign,1,1])
  multmatrix([[1,0,0,0],[0,0,-1,boss_y/2],[0,1,0,0],[0,0,0,1]])
  linear_extrude(boss_y)polygon([[guide_gap/2,deck_depth-.2],[boss_x/2,deck_depth-.2],
   [boss_x/2,deck_depth],[6.5,deck_depth+2],[6.5,deck_depth+guide_depth],
   [guide_gap/2,deck_depth+guide_depth]]);
}
module top(){difference(){union(){
 linear_extrude(skin)outline();
 translate([0,0,skin-.2])linear_extrude(rim_depth-skin+.2)perimeter();
 // Continuous left-right beams; roof/skin acts as their upper flange in service.
 for(y=[49,85,121])cuboid([3,y-2.5,skin-.2],[top_x-3,y+2.5,deck_depth]);
 // Cross-ribs spread heel pressure and connect the beams and perimeter.
 for(x=[22,71,120,169,218])cuboid([x-1.8,3,skin-.2],[x+1.8,top_y-3,rim_depth]);
 for(sx=support_x)for(cy=slot_y){
  cuboid([sx-boss_x/2,cy-boss_y/2,skin-.2],[sx+boss_x/2,cy+boss_y/2,deck_depth]);
  guide(sx,cy);
 }
}
 // Blind sockets OPEN UP in print orientation, roof at z=9 mm.
 // Full 7 mm straight engagement; no pocket cuts through a socket wall.
 for(sx=support_x)for(cy=slot_y)
  cuboid([sx-slot_t/2,cy-slot_w/2,deck_depth-engagement],[sx+slot_t/2,cy+slot_w/2,deck_depth+.01]);
}}
module socket_coupon(){translate([-11,-31,0])intersection(){top();cuboid([11,31,0],[33,67,25]);}}
module tab_coupon(){translate([-23,-(H-frame),0])intersection(){support();cuboid([23,H-frame,0],[55,H+tab_h,T]);}}
module foot_local(){difference(){union(){
 cuboid([-1.8,-2,-2.05],[28,0,9.05]);
 cuboid([-1.8,-.1,-2.05],[28,9,-.25]);
 cuboid([-1.8,-.1,7.25],[28,14,9.05]);
 cuboid([-1.8,-.1,-2.05],[-.25,9,9.05]);
}xy_prism([[8.75,2.75],[19.25,2.75],[19.25,7.25],[15,11.5],[13,11.5],[8.75,7.25]],7,12);}}
module foot_print(){translate([1.8,9.05,2])rotate([90,0,0])foot_local();}
module place_support(sx){translate([sx-T/2,support_y0,sole])rotate([90,0,90])children();}
module place_top(){translate([0,top_y,total_height])rotate([180,0,0])children();}
module assembly(){
 color("silver")place_top()top();
 color("steelblue")place_brace()rear_brace();
 for(sx=support_x)place_support(sx){
  color("slategray")support();
  color("peru"){foot_local();translate([W,0,0])mirror([1,0,0])foot_local();}
 }
}
if(part=="top")top();
else if(part=="support")support();
else if(part=="brace")rear_brace();
else if(part=="brace_socket_coupon")brace_socket_coupon();
else if(part=="brace_tab_coupon")brace_tab_coupon();
else if(part=="socket_coupon")socket_coupon();
else if(part=="tab_coupon")tab_coupon();
else if(part=="foot_left")foot_print();
else if(part=="foot_right")translate([29.8,0,0])mirror([1,0,0])foot_print();
else if(part=="assembly")assembly();
else assert(false,"Unknown part selector");

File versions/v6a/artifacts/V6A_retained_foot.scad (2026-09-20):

// V6A experimental retained TPU foot. Units: mm.
// Default is ONE PLA coupon. Read V6A_README.md before printing.
// Full support preserves V5 height: with 2 mm sole assembled height is 243 mm.
// Full support is reference-only pending foot test and top/height reconciliation.
part = "coupon"; // coupon, foot, coupon_assembly, support_reference, support_assembly
$fn=48;

// Unchanged V5 geometry from original source.
W=150; H=234; T=7; frame=10; brace=8;
tab_w=22; tab_h=7; tab_t=7; tab_centers=[39,111];
module beam2d(x1,y1,x2,y2,w) {
 hull() { translate([x1,y1]) circle(d=w); translate([x2,y2]) circle(d=w); }
}
module frame2d() {
 union() {
  square([W,frame]); translate([0,H-frame]) square([W,frame]);
  translate([0,frame]) square([frame,H-2*frame]);
  translate([W-frame,frame]) square([frame,H-2*frame]);
  beam2d(frame-5,frame-5,W-frame+5,H-frame+5,brace);
  beam2d(W-frame+5,frame-5,frame-5,H-frame+5,brace);
  for(p=[[frame,frame],[W-frame,frame],[frame,H-frame],[W-frame,H-frame]])
   translate(p) circle(d=14);
 }
}
module base_support() {
 union() {
  linear_extrude(T) frame2d();
  for(c=tab_centers) translate([c-tab_w/2,H,0]) cube([tab_w,tab_h,tab_t]);
 }
}
// x along rail, y upward, z through rail thickness. Underside of rail: y=0.
sole=2;
wall=1.8;
clearance=0.25; // per face, UNCALIBRATED TPU trial; independent of PLA socket fit
catch_projection=2.2;
foot_length=28;
module cuboid(a,b) {translate(a) cube(b-a);}
module xy_prism(points,z0,z1) {translate([0,0,z0]) linear_extrude(z1-z0) polygon(points);}
module yz_prism(points,x0,x1) {
 multmatrix([[0,0,1,x0],[1,0,0,0],[0,1,0,0],[0,0,0,1]])
 linear_extrude(x1-x0) polygon(points);
}
module catch_left() {
 // 0.2 mm root overlap guarantees a volumetric connection.
 // 45 degree insertion ramp; roof follows TPU window for distributed retention.
 intersection() {
  yz_prism([[3,6.8],[11.25,6.8],[11.25,7+catch_projection],
            [3+catch_projection,7+catch_projection],[3,7]],9,19);
  xy_prism([[9,3],[19,3],[19,7.25],[15,11.25],[13,11.25],[9,7.25]],6.7,10);
 }
}
module support_new() {
 union() {
  base_support(); catch_left();
  translate([W,0,0]) mirror([1,0,0]) catch_left();
 }
}
module coupon() {intersection() {support_new();cuboid([0,0,0],[32,22,12]);}}
module foot_local() {
 difference() {
  union() {
   cuboid([-wall,-sole,-clearance-wall],[foot_length,0,7+clearance+wall]);
   cuboid([-wall,-.1,-clearance-wall],[foot_length,9,-clearance]);
   cuboid([-wall,-.1,7+clearance],[foot_length,14,7+clearance+wall]);
   cuboid([-wall,-.1,-clearance-wall],[-clearance,9,7+clearance+wall]);
  }
  // 45 degree roof narrows final bridge to 2 mm for sole-down printing.
  xy_prism([[9-clearance,3-clearance],[19+clearance,3-clearance],
            [19+clearance,7.25],[15,11.25+clearance],
            [13,11.25+clearance],[9-clearance,7.25]],7,12);
 }
}
module foot_print() {
 translate([wall,7+clearance+wall,sole]) rotate([90,0,0]) foot_local();
}
if(part=="coupon") coupon();
else if(part=="foot") foot_print();
else if(part=="coupon_assembly") {
 color("lightgray") coupon(); color("peru") foot_local();
} else if(part=="support_reference") support_new();
else if(part=="support_assembly") {
 color("lightgray") support_new();
 color("peru") {foot_local();translate([W,0,0]) mirror([1,0,0]) foot_local();}
} else assert(false,"Unknown part selector");

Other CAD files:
versions/v9c-fit/artifacts/V9C_channel_0p20_PLA.stl
current/TPU95A/05_foot_A_PRINT_2.stl
versions/v8b/artifacts/V8B_trial_keeper.stl
versions/v9-full/artifacts/reference/tested_brace_context.stl
versions/v9-full/artifacts/V9_brace_PLA_PROTOTYPE.stl
versions/v10a-print-prototype/V10A_prototype.scad
current/PLA/01_top_PRINT_1.stl
current/PLA/02_left_support_PRINT_1.stl
versions/v6a/artifacts/reference/flatpack_footrest_v3.scad
versions/v6a/artifacts/reference/flatpack_footrest_v3_top.stl
versions/v6a/artifacts/reference/flatpack_footrest_v5_light_support.scad
versions/v6a/artifacts/reference/flatpack_footrest_v5_tpu_foot.scad
versions/v6a/artifacts/reference/footrest_tolerance_coupon_v6_7mm_sockets_only.stl
versions/v7/artifacts/PRINT_FIRST_brace_socket_coupon.stl
versions/v7/artifacts/PRINT_FIRST_brace_tab_coupon.stl
versions/v7/artifacts/PRINT_FIRST_top_socket_coupon.stl
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

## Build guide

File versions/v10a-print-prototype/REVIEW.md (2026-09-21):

# V10A prototype STL release

Parent: V10 side-entry concept. User explicitly requested STLs after discussion of unresolved fit/top restraint. Created 2026-09-20.

Change: export distinct left/right supports and brace in print orientations. Extend rear socket block bases to the original flat support faces to eliminate elevated block starts. Mating geometry and existing top unchanged.

Checks run: source rendered with OpenSCAD; single watertight consistently wound components; print-bed bounds; assembly, support insertion and top installation paths; fixed-top obstruction probes; print/world inverse-transform regression with measured sub-micron STL rounding. Full results in geometry_checks.json.

Physical evidence: none for this new design. Prior V9C clearance success is not a new socket fit pass. Top-lift and racking remain unresolved. No claim of structural acceptance. TPU handedness is pending.

Release: full STLs supplied on user's request as a prototype; recommend one support plus brace first to limit wasted material. Next test is local seating/removal, then assembled racking and top lift. See START_HERE.md.

## Physical update — 2026-09-21

User reports: “v10 seems to have solved racking for the most part” and “it feels way more stable.” Recorded against the supplied V10A print release, called V10 by the user; exact file hashes of printed parts were not reconfirmed.

This is qualitative assembled stability improvement relative to V9/V2. It supports continuing with the side-entry mechanism rather than another redesign. It is consistent with improved vertical restraint at brace joints, but does not isolate the effects of changed fit, socket geometry or support stiffness.

Not reported: applied force, residual displacement, whether the top lifts, measured loading, sustained load duration, assembly/removal cycling, TPU installation or damage inspection. Do not infer these passed. Next check: comfortable intentional disassembly/reassembly and retention of the improved seating/stability. No geometry changed for this result.

## Physical update — 2026-09-21, fully seated top removal

User reports that after fully pushing the top in, pulling it straight out feels locked; angling it somewhat helps removal. The top has no intentional latch. Record this as difficult removal/binding, not a successful positive lock. Which connection binds, applied force and any damage are not established. Possible four-joint alignment, friction or guide contact are hypotheses, not diagnoses. Do not recommend forceful prying. Packability remains unresolved despite the improved racking feedback. No geometry changed.

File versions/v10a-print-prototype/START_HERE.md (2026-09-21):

# V10A — user-requested prototype STLs

Print one LEFT support, one RIGHT support and one BRACE. Reuse the existing V7/V9 top. These supports replace the old T-rail supports; do not mix the two joint systems. Left and right are distinct files, not two copies of the old identical support.

- V10A_left_PLA_PROTOTYPE.stl: 163 x 230 x 23.5 mm.
- V10A_right_PLA_PROTOTYPE.stl: 163 x 230 x 23.5 mm.
- V10A_brace_PLA_PROTOTYPE.stl: 180 x 180 x 8 mm.

All are PLA and already oriented on z=0. Keep the supplied orientations. Each support's sockets open upward in print; the brace lies flat with the tongue/back faces on the bed. Use your established PLA profile; prior baseline was 0.4 mm nozzle, 0.2 mm layers, six walls, six top/bottom layers and 20–30% infill. This new fit/orientation has NOT been physically calibrated. Inspect sliced pockets, roofs and walls, and filament estimate before printing. No slicer/toolpath validation was performed. No support material is intended inside the sockets.

For lowest waste, print one support and the brace first, assess both tongue fits by hand, then print the other support if they seat and release comfortably. The first partial assembly is not a load test. Do not hammer, force or substantially sand the joint to make it fit. Nominal socket clearance is 0.15 mm per face, but the earlier 0p15 C-channel result does not validate these new rectangular sockets.

Assembly: top off; hold brace between supports; move the supports inward over the tongues; then install the top. Both socket pairs face inward. To disassemble, remove the top and move the supports apart. The tongues have 12 mm nominal engagement and 2 mm blind-end gap. The joint does not depend on a wedged friction fit.

Before foot load, gently assess assembled sideways racking and watch for top lifting, support spreading, joints unseating or damage. Stop on any of those observations. The top is still unlatched; coupled top-lift/splay and member flex have not been solved or validated. This is an experimental release requested by the user, not a verified fix or a 200 N rating. Do not stand on it.

The mirrored support arrangement requires checking existing TPU shoe handedness/orientation before reuse. No new TPU shoe is included or declared validated. Keep floor slip distinct from joint racking in observations.

## Change from V10 concept

Socket blocks now extend from x=18.5 instead of x=22 on the left (mirrored on the right), reaching the original flat bed face. This avoids starting the projecting block 3.5 mm above the bed. Socket voids, tongues, top and engagement are unchanged. Added material is external to the original rail; strength is not quantified.

## Checks

World-coordinate assembly checks rerun: no nominal interference in assembled state, side-entry path (0.25 mm steps), or top installation (0.5 mm steps). Fixed-top rigid blocking tests remain conditional on the top staying seated. All print exports reload as single watertight components with consistent winding and positive volume, and fit the A1 object envelope. Reverse transforms match world meshes to STL coordinate rounding: maximum nearest-vertex error 0.0005 mm; volume symmetric differences under 1 mm³ on ~102,000 mm³ supports. See geometry_checks.json. No FEA, physical fit, load, fatigue, creep or TPU-regression claim is made.

Source V10A_prototype.scad uses reference/V7.scad. Select left_print, right_print or brace_print for the printable orientations. Other selectors are world-coordinate reference parts, not print-oriented exports. validation_workspace.py records the checks and depends on work/v10a renders in the original project workspace.

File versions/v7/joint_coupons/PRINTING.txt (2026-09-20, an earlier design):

V7 first prints: four small PLA parts forming two joint tests. About 27 g fully solid total.
All parts are already oriented for printing. Keep millimetres and do not scale.
These can share one PLA plate: no TPU or prime tower is needed.
For the smallest first commitment, print the top socket/tab pair first (about 15.3 g), then the brace pair (about 11.7 g).
Assuming a 0.4 mm nozzle: use your proven PLA profile, 0.20 mm layers, six walls, six top/bottom layers, 20-30% infill as a starting point. Check actual toolpaths.
Supports are not intended. Inspect the 22.1 mm bridge over the brace socket; sagging could obstruct the tight fit.
Insert each tab until its shoulder/pad seats. It should assemble and release by hand with little rocking. Cycle 10 times and inspect for damage.
Report fit, full seating, rocking, brace-roof quality and slicer grams/time before printing large parts.
The top and rear brace remain structural prototypes, not load-rated parts. See the full V7 package for engineering notes and limitations.

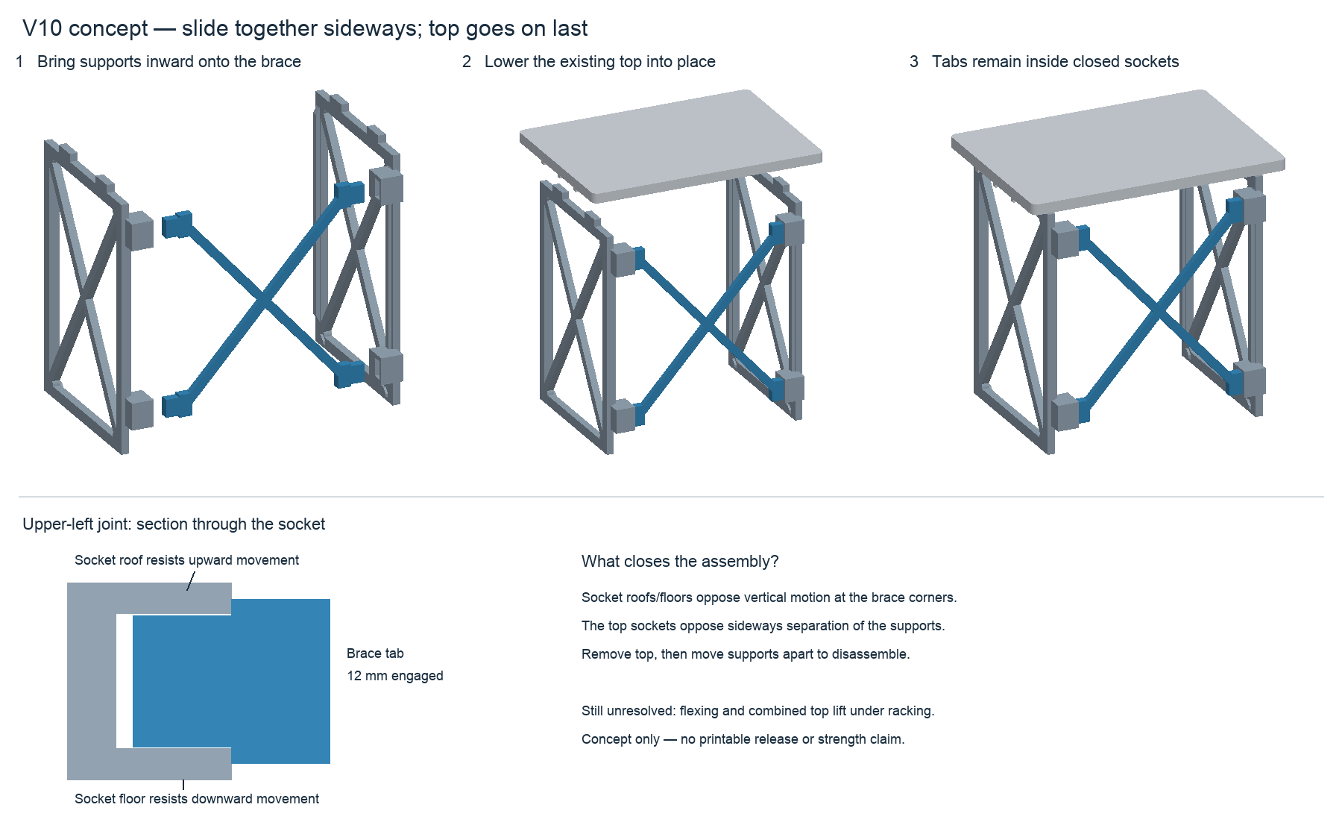
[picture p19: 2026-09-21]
versions/v10-side-entry-concept/V10_assembly_sequence.png

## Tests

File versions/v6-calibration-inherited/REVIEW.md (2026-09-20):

# Inherited V6 top-joint tolerance calibration

Stage: `v6-calibration-inherited`. Previous recorded stage: `v5-inherited`. Retrospectively documented 2026-09-20.

## Change and reason

Preserved historical calibration artifact. This is a tolerance coupon, not a V6 full assembly. Selected 7 x 22 mm tab into 7.10 x 22.10 mm socket with 7 mm engagement.

## Recorded CAD/analysis evidence

Later parser inspection reported non-watertight geometry and 24 components; this does not negate the historical physical fit observation.

## User-reported physical evidence

Handoff: +0.30 mm total still wobbly; +0.10 and +0.20 had similar low true play; +0.10 slightly harder to dislodge and selected. +0.50 previously too loose.

## Outcome and next question

Preserve calibrated top interface. Do not assume it transfers to differently oriented rear joints or TPU interfaces.

## Provenance caveat

Copied artifacts and archives are preserved as found. Some source READMEs contain later annotations or stale release instructions. This review and repository STATUS take precedence for interpreting current experimental status. No CAD or physical tests were rerun during this history import.

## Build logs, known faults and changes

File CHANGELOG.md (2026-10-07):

# Changelog — retrospective, chronological

Design sequence is reconstructed from artifacts and conversation. Outcomes include later observations; no claim that they were known at original release. Dates of individual prints were not consistently recorded.

## v3-inherited — Inherited V3 top and assembly concept

**Change / why:** Imported the older top/assembly reference supplied with the handoff. Approximate 230 x 170 mm top; not reconciled to the latest support.

**CAD:** Later V6A inspection reported five disconnected top bodies (platform plus four socket bosses), despite watertightness. That finding belongs to the later inspection, not an original V3 test.

**Physical:** No full V3 top test result is available in this conversation.

**Outcome:** Reference only. Required connected socket bosses, support reconciliation and height review. Handoff also mentions unavailable V4 and earlier disconnected-brace failures.

[Artifacts and review](versions/v3-inherited/REVIEW.md)

## v5-inherited — Inherited V5 lightweight support and friction shoe

**Change / why:** Inherited 10 mm perimeter rails, 8 mm X members, 7 mm thickness and local junction pads. Handoff describes reduction from unavailable V4 (12 mm rails/10 mm braces). Existing TPU shoe relied on friction only.

**CAD:** Handoff reports a connected support and roughly 80.17 cm³ volume. Later V6A checks preserved the full bottom rail. No structural rating was established.

**Physical:** No standalone V5 structural load result is available. User requested proper replaceable TPU retention.

**Outcome:** Use as structural starting point; replace friction-only foot interface without cutting the rail.

[Artifacts and review](versions/v5-inherited/REVIEW.md)

## v6-calibration-inherited — Inherited V6 top-joint tolerance calibration

**Change / why:** Preserved historical calibration artifact. This is a tolerance coupon, not a V6 full assembly. Selected 7 x 22 mm tab into 7.10 x 22.10 mm socket with 7 mm engagement.

**CAD:** Later parser inspection reported non-watertight geometry and 24 components; this does not negate the historical physical fit observation.

**Physical:** Handoff: +0.30 mm total still wobbly; +0.10 and +0.20 had similar low true play; +0.10 slightly harder to dislodge and selected. +0.50 previously too loose.

**Outcome:** Preserve calibrated top interface. Do not assume it transfers to differently oriented rear joints or TPU interfaces.

[Artifacts and review](versions/v6-calibration-inherited/REVIEW.md)

## v6a — V6A mechanically retained TPU foot

**Change / why:** Added external PLA corner catches and mating TPU window shoes, keeping the bottom rail intact. Replaced friction-only retention with an intentional peel-to-release interface.

**CAD:** Recorded component/watertightness checks, material-preservation booleans, nominal contacts, rigid blocking checks and independent SCAD export comparison. Found inherited disconnected top bosses and 243 mm provisional height with sole.

**Physical:** User printed shoe and PLA key/coupon, reported it fit and passed the tests. Small internal gap opposite the key slot was reported. Exact forces and per-test cycle counts were not supplied.

**Outcome:** Local TPU interface accepted for reuse; not full-structure validation. Next reconcile top/height and across-width bracing.

[Artifacts and review](versions/v6a/REVIEW.md)

## v7 — V7 ribbed 240 mm top and rear X brace

**Change / why:** Chose 240 x 170 mm one-piece top for A1 bed rather than wider split platform. Added connected rib/boss top, shortened support for nominal 241 mm height, rail stiffeners and rear X brace. Rear joint repeated a tight 7 x 22 x 7 interface. User measured heel spread about 12 inches and seated load about 25.6 lb; 200 N remained an unproven check target.

**CAD:** Recorded topology, exact tab/socket and rail checks, assembly/insertion booleans, orientation review, rebuild checks and idealized structural screens. These screens were not measured full-frame stiffness or strength.

**Physical:** Top and rear coupons fit with effort. Full rear brace/support slid in then tightened/snapped; could not be removed by hand. Pulling later broke the rear key/tab inside support; user discarded both. Photo/orientation review did not identify reversed assembly as the cause. Reported slicer masses: rear 26 g, supports 54 g each, top 161.41 g.

**Outcome:** Rear connection failed packability/removal. Top and TPU interfaces subsequently retained. Do not reuse tight rear fit; geometry validity did not establish removability.

[Artifacts and review](versions/v7/REVIEW.md)

## v8 — V8 sliding tongue and loose quarter-turn keeper

**Change / why:** Separated structural sliding tongue (0.30 mm per face) from quarter-turn withdrawal keeper. Added lift-to-turn locating posts and exposed grip to avoid forceful disassembly.

**CAD:** Recorded connected watertight meshes, sampled insertion/lift/rotation/extraction paths and deliberate blocking collisions. No load validation.

**Physical:** No successful printed V8 trial reported. User flagged four loose keys as a loss/usability issue; print was canceled as the design changed.

**Outcome:** Abandoned before physical validation. Added operations/loose parts were unacceptable for packing.

[Artifacts and review](versions/v8/REVIEW.md)

## v8b — V8B tether-eyelet keeper trial

**Change / why:** Added receiver/keeper eyelets for cord retention. Initially considered TPU tether, but actual deliverable assumed cord; no TPU tether attachment was validated. Provisional rearward locations studied for key access.

**CAD:** Recorded joint mesh/path checks and four provisional key-clearance paths against top/support core. Attachment webs, full brace integration, tether motion and human access were not complete.

**Physical:** No physical V8B pass reported. User questioned increasing complexity; assistant agreed keys/posts/tethers were overcomplicating the problem.

**Outcome:** Abandoned. Return to whole-assembly sequence and simpler connections rather than iterating an elaborate lock.

[Artifacts and review](versions/v8b/REVIEW.md)

## v9-trial — V9 drop-in T/C coupon and full-layout concept

**Change / why:** Adopted four short T rails with C channels, fixed lower seating ledges and 20 mm vertical engagement. No latch. Beveled 45-degree shoulders for flat-print geometry; 0.30 mm per axis face. Narrowed ledge after detecting diagonal interference.

**CAD:** Recorded connected coupon/support/brace meshes, full approach/vertical paths and top install checks. Existing top explicitly did not block lift-off. Strength, uplift and four-point physical fit remained unknown.

**Physical:** Coupon slid easily and remained wrapped during X/Y motion, with some rocking. User highlighted looseness. This was a local fit test only.

**Outcome:** Advanced to full prototype without proof of racking restraint. Later failures showed that easy fit and wraparound engagement were insufficient.

[Artifacts and review](versions/v9-trial/REVIEW.md)

## v9-full — V9 full assembly with backed rail roots

**Change / why:** Kept coupon contact geometry; added backing at each T root, with roughly 183 mm³ net added per support. Released full support/brace and unchanged top/TPU parts.

**CAD:** Recorded full topology/bed checks, four-joint assembly/removal and top installation, TPU nominal intersections, plus top/brace regressions. Root review was qualitative, not strength qualification.

**Physical:** One support plus brace slid smoothly but swayed; user flagged this before printing second. Assistant expected the second support to constrain it. Complete assembly without TPU feet racked with all floor corners touching. Upper C channels slid upward off T rails; they did not spread/pop backward. User described the frame becoming a parallelogram.

**Outcome:** FAILED assembled racking/retention. Earlier confidence in the second support was unsupported. Floor grip was not the identified cause. Keep top/supports for experiments, not as a rated structure.

[Artifacts and review](versions/v9-full/REVIEW.md)

## v9c-fit — V9C brace-side clearance coupons

**Change / why:** Reduced only channel clearance to 0.20 and optional 0.15 mm per face, maintaining engagement, exterior, supports and top. No anti-lift stop added. Goal: distinguish excess clearance from the unrestricted release direction.

**CAD:** Recorded original-0.30 reproduction, single-solid tighter exports, added-material-only check, and nominal approach/vertical paths against support rail positions. No revised full-frame test at this stage.

**Physical:** User reported 0p15 felt pretty good and authorized full bracket V2. Separate 0p20 result and explicit all-four-rail/cycle confirmation were not supplied.

**Outcome:** Local 0p15 fit selected. This did not prove racking or lift-off solved.

[Artifacts and review](versions/v9c-fit/REVIEW.md)

## v9-bracket-v2 — V9 bracket V2 with four 0p15 channels

**Change / why:** Applied tested 0.15 mm fit to all four brace channels; X, spacing, top and supports unchanged. No anti-lift feature. About 0.53 g solid PLA added over prior brace.

**CAD:** Recorded one watertight component, A1 envelope, nominal assembly/removal/top-install checks. Regression against old brace plus four tighter coupons differed 0.00994 mm³ within documented 0.02 mm³ numerical tolerance.

**Physical:** User printed V2: more stable, but during left/right racking the upper channels again slid up off the T rails. User emphasized that the brace still does not prevent racking.

**Outcome:** FAILED full-frame racking/retention despite improved local fit. Further tightening is not the established fix. Open question: when does vertical channel motion begin relative to frame racking? A proposed anti-lift feature must carry load and constrain racking, not merely catch a detached brace.

[Artifacts and review](versions/v9-bracket-v2/REVIEW.md)

## v10-side-entry-concept — horizontal sockets captured by support spacing

**Change / why:** Following V2 racking/lift-off, move the brace release direction sideways. Inward-facing support sockets have closed roofs/floors; the top is intended to constrain support separation. Top geometry retained, support rear interfaces open to redesign, no purchased fasteners. No further V9 clearance adjustment.

**CAD:** New concept model, assembly sequence and joint section. Connected watertight components; sampled sideways assembly and top installation clear. Deliberate upward/downward brace motion and outward support motion with the top fixed meet geometry. Reports do not establish coupled top-lift restraint, strength or real stiffness.

**Physical:** Not printed or tested. No new print files released.

**Outcome:** Candidate for discussion. Capture depends on the top remaining seated; flexing, combined lift/splay, new fit, print orientation and mirrored support/TPU arrangement remain open. [Concept review](versions/v10-side-entry-concept/REVIEW.md).

## v10a-print-prototype — requested full STLs

**Change / why:** User requested V10 STLs. Added flat-face backing to socket blocks for printing, retained mating geometry, and exported separate left/right supports and rear brace. Existing top retained.

**CAD:** Reran rigid assembly/path checks; verified print exports, orientation regression and A1 envelopes. No sliced toolpaths or structural qualification.

**Physical:** Untested. New rectangular socket fit, combined top lift/racking and TPU handedness remain unresolved. This prototype release does not supersede V9/V2 failure evidence with a claimed pass.

[Files and instructions](versions/v10a-print-prototype/START_HERE.md).

## 2026-09-21 — V10/V10A assembled feedback

User reports racking mostly resolved and assembly feels much more stable. Qualitative full-assembly improvement; no measured force/displacement, load-capacity or durability result. Preserve geometry for further evaluation. Added physical result to V10A review; no new design version.

## 2026-09-21 — fully seated top binds during removal

V10A user feedback: fully seated top resists straight extraction; angling helps. No designed latch exists. Stability improvement remains reported, but easy disassembly is not established. Record binding/alignment/friction as possible causes, pending localization; no design change made.

## 2026-10-07 — complete current print set

Added current/ with unchanged V10A supports/brace, retained V7 top and V6A-derived TPU shoes. Quantities are encoded in filenames and documented. Confirmed existing A/B feet can occupy all four mirrored-support positions with proper rotations/translations and zero nominal structural interference. Two A plus two B; no new geometry. Physical fit on V10A remains unreported. Provenance hashes link every current print to its historical source.

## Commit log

2026-09-20 v3-inherited: Inherited V3 top and assembly concept
    Retrospective import of available artifacts and reported outcomes; original timestamps are not reconstructed.
    [flatpack_footrest_v3.scad, flatpack_footrest_v3_top.stl]
2026-09-20 v6a: V6A mechanically retained TPU foot
    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
    [V6A_PLA_corner_coupon.stl, V6A_TPU95A_test_foot.stl, V6A_retained_foot.scad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]
2026-09-20 v6-calibration-inherited: Inherited V6 top-joint tolerance calibration
    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
    [footrest_tolerance_coupon_v6_7mm_sockets_only.stl]
2026-09-20 v5-inherited: Inherited V5 lightweight support and friction shoe
    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
    [flatpack_footrest_v5_light_support.scad, flatpack_footrest_v5_light_support.stl, flatpack_footrest_v5_tpu_foot.scad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]
2026-09-20 v8: V8 sliding tongue and loose quarter-turn keeper
    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
    [V8_rear_joint_trial.scad, V8_trial_keeper.stl, V8_trial_receiver.stl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]
2026-09-20 v7: V7 ribbed 240 mm top and rear X brace
    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
    [PRINT_FIRST_brace_socket_coupon.stl, PRINT_FIRST_brace_tab_coupon.stl, PRINT_FIRST_top_socket_coupon.stl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]
2026-09-20 v9c-fit: V9C brace-side clearance coupons
    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
    [V9C_channel_0p15_PLA.stl, V9C_channel_0p20_PLA.stl, V9C_channel_fit.scad]
2026-09-20 v9-trial: V9 drop-in T/C coupon and full-layout concept
    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
    [PRINT_FIRST_V9_channel_coupon.stl, PRINT_FIRST_V9_rail_coupon.stl, V9_drop_in_trial.scad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]
2026-09-20 v9-full: V9 full assembly with backed rail roots
    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
    [V9_brace_PLA_PROTOTYPE.stl, V9_foot_left_TPU95A.stl, V9_foot_right_TPU95A.stl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]
2026-09-20 v8b: V8B tether-eyelet keeper trial
    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
    [V8B_rear_joint_trial.scad, V8B_trial_keeper.stl, V8B_trial_receiver.stl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]
2026-09-20 v9-bracket-v2: V9 bracket V2 with four 0p15 channels
    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
    [PRINT_V9_bracket_V2_0p15_PLA.stl, V9_bracket_V2_0p15.scad]
2026-09-21 v10: explore side-entry brace sockets and document conditional top capture
    [V10_concept.scad, V7.scad]
2026-09-21 v10a: export requested prototype STLs with bed-supported socket bases
    [V10A_brace_PLA_PROTOTYPE.stl, V10A_left_PLA_PROTOTYPE.stl, V10A_prototype.scad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]
2026-09-21 test(v10a): record improved assembled stability reported by user
2026-10-07 organize: add complete current V10A print set and verify foot placement
    [01_top_PRINT_1.stl, 02_left_support_PRINT_1.stl, 03_right_support_PRINT_1.stl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]
